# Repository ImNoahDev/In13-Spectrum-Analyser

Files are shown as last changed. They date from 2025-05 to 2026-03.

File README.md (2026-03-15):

# Nixie tube spectrum analyser

Warning: this is currently untested

I have designed an audio spectrum analyser that breaks an audio signal down into 7 frequency bands and displays each band on an in13 nixie tube. My project has Wifi allowing for smart home control. My project has a volume (changes sensitivity) and a brightness potentiometer. Each PCB takes a single audio signal input and 2 can be used for full stereo.

The case uses a laser cut kerf bend to allow the wrap around sheet to be cut in a single part. 

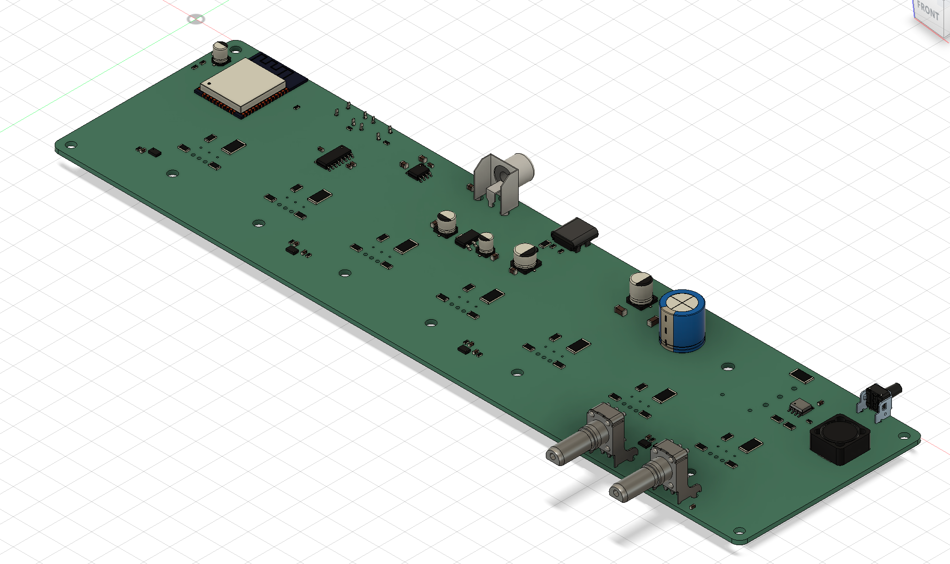
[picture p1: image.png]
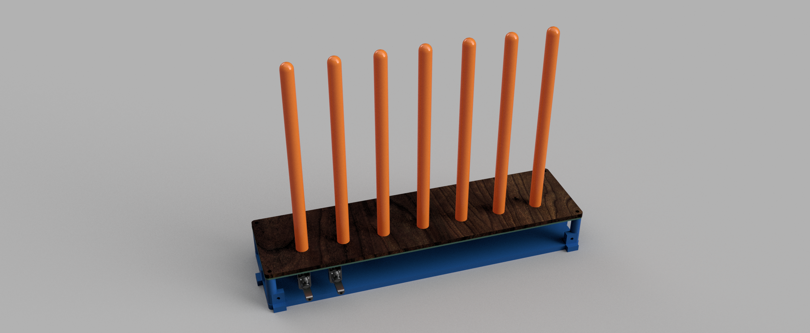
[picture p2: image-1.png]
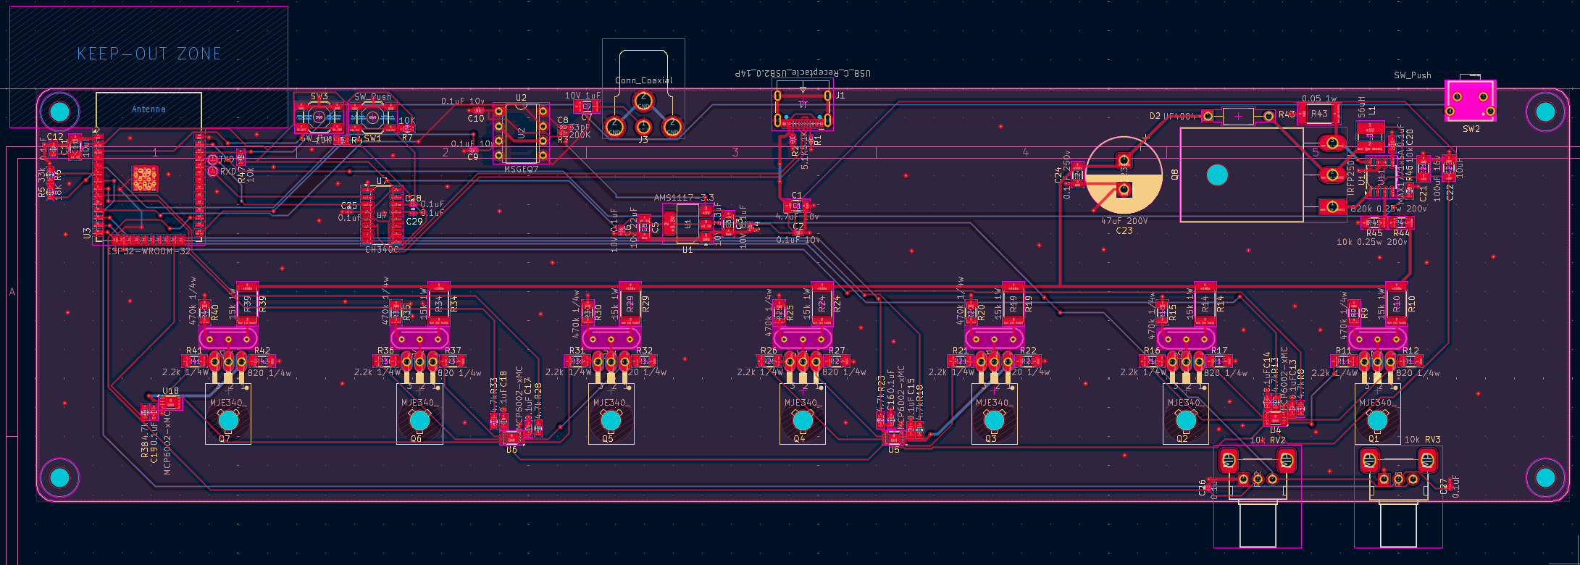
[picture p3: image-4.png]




## Assembly instructions.

First manufacture and assemble the PCB according to the KiCad files. Next 3d print the top and bottom parts of the case. place the PCB onto the standoffs of the case with layer B (with the least components) facing upwards. Place the top of the case on and screw all part onto the standoffs. Laser cut the Wrap around and screw it in to the bottom mounting holes of the case while wrapping around the case to give a wooden front finish.

Code can be flashed through the USB port due to the built in USB-Serial converter.

## BOM

Note this is for 2x units (Left and Right) because most PCB manufacturers require at least 2 assembled and the price is not significantly more for 2 vs 1. This allows one per audio channel. The price of the tubes also wildly swings so I have put a placeholder value in that is roughly correct (depending on where you get them).

| Part name | Cost | Use | URL |
| --- | --- | --- | --- |
| PCB Manufacture | $11.20  | PCB | jlpcb.com |
| Economic PCBA | $66.22  | Assemble PCB | jlpcb.com |
| Components (PCBA) | $61.93  | Components for PCBA | jlpcb.com |
| Shipping | $15 | PCB shipping | jlpcb.com |
| In13 tubes | $200 | Tubes | Ebay |
| Total: | $343.35 | | |

| Comment | Designator | Footprint | Quantity |
| --- | --- | --- | --- |
| MJE340_ | Q4 | TO126 | 1 |
| 10uF | C22 | C_1206_3216Metric | 1 |
| 4.7k | R38 | R_0603_1608Metric | 1 |
| 15k 1W | R14 | R_2512_6332Metric | 1 |
| 820k 0.25w 200v | R44 | R_1206_3216Metric | 1 |
| 820 1/4w | R22 | R_1206_3216Metric | 1 |
| 0.1uF | C28 | C_0201_0603Metric | 1 |
| 10v 22uF | C5 | C_1206_3216Metric | 1 |
| 10uF | C11 | C_1206_3216Metric | 1 |
| 15k 1W | R34 | R_2512_6332Metric | 1 |
| USB_C_Receptacle_USB2.0_14P | J1 | USB_C_Receptacle_HCTL_HC-TYPE-C-16P-01A | 1 |
| SW_Push | SW2 | 4312560387X6 | 1 |
| MJE340_ | Q2 | TO126 | 1 |
| 4.7k | R8 | R_0603_1608Metric | 1 |
| 0.05 1w | R43 | R_2512_6332Metric | 1 |
| 0.1uF | C15 | C_0603_1608Metric | 1 |
| ESP32-WROOM-32 | U3 | ESP32-WROOM-32 | 1 |
| 15k 1W | R19 | R_2512_6332Metric | 1 |
| 2.2k 1/4W | R26 | R_1206_3216Metric | 1 |
| 0.1uF | C27 | C_0201_0603Metric | 1 |
| 0.1uF | C13 | C_0603_1608Metric | 1 |
| 2.2k 1/4W | R16 | R_1206_3216Metric | 1 |
| 2.2k 1/4W | R36 | R_1206_3216Metric | 1 |
| 10k | RV2 | Potentiometer_Alps_RK09K_Single_Horizontal | 1 |
| MSGEQ7 | U2 | DIP-8_W7.62mm | 1 |
| 0.1uf | C25 | C_0201_0603Metric | 1 |
| SW_Push | SW3 | SW_SPST_SKQG_WithStem | 1 |
| 4.7k | R33 | R_0603_1608Metric | 1 |
| 820 1/4w | R37 | R_1206_3216Metric | 1 |
| MCP6002-xMC | U5 | DFN-8-1EP_3x2mm_P0.5mm_EP1.75x1.45mm | 1 |
| 2.2k 1/4W | R31 | R_1206_3216Metric | 1 |
| IRFP250N | Q8 | TO-247-3_Horizontal_TabDown | 1 |
| 56 uH | L1 | L_Ferrocore_DLG-0403 | 1 |
| 10k | R46 | R_0603_1608Metric | 1 |
| 200K | R3 | R_0402_1005Metric | 1 |
| 4.7k | R18 | R_0603_1608Metric | 1 |
| 820 1/4w | R27 | R_1206_3216Metric | 1 |
| MJE340_ | Q1 | TO126 | 1 |
| 0.1uF 10v | C10 | C_0402_1005Metric | 1 |
| 4.7k | R23 | R_0603_1608Metric | 1 |
| MJE340_ | Q6 | TO126 | 1 |
| 4.7uF 10v | C1 | C_1206_3216Metric | 1 |
| 15k 1W | R24 | R_2512_6332Metric | 1 |
| 10K | R7 | R_0603_1608Metric | 1 |
| MJE340_ | Q3 | TO126 | 1 |
| 0.1uF | C14 | C_0603_1608Metric | 1 |
| 0.1uF | C19 | C_0603_1608Metric | 1 |
| 0.1uF | C26 | C_0201_0603Metric | 1 |
| 100uF 16v | C21 | C_1206_3216Metric | 1 |
| 10V 1uF | C7 | C_1206_3216Metric | 1 |
| 10V 0.1uF | C4 | C_0402_1005Metric | 1 |
| MCP6002-xMC | U4 | DFN-8-1EP_3x2mm_P0.5mm_EP1.75x1.45mm | 1 |
| 0.1uF | C17 | C_0603_1608Metric | 1 |
| 470k 1/4w | R40 | R_1206_3216Metric | 1 |
| 820 1/4w | R42 | R_1206_3216Metric | 1 |
| 0.1uF | C16 | C_0603_1608Metric | 1 |
| 10k 0.25w 200v | R45 | R_1206_3216Metric | 1 |
| 15k 1W | R10 | R_2512_6332Metric | 1 |
| 470k 1/4w | R20 | R_1206_3216Metric | 1 |
| 47uF 200V | C23 | CP_Radial_D13.0mm_P5.00mm | 1 |
| SW_Push | SW1 | SW_SPST_SKQG_WithStem | 1 |
| RXD | TP2 | TestPoint_Pad_D1.0mm | 1 |
| 10K | R4 | R_0603_1608Metric | 1 |
| 5.1K | R1 | R_0402_1005Metric | 1 |
| 470k 1/4w | R25 | R_1206_3216Metric | 1 |
| 820 1/4w | R17 | R_1206_3216Metric | 1 |
| 470k 1/4w | R30 | R_1206_3216Metric | 1 |
| 10V 0.1uF | C6 | C_0402_1005Metric | 1 |
| 5.1K | R2 | R_0402_1005Metric | 1 |
| 470k 1/4w | R15 | R_1206_3216Metric | 1 |
| 0.1uF 10v | C9 | C_0402_1005Metric | 1 |
| 4.7k | R13 | R_0603_1608Metric | 1 |
| 10k | R47 | R_0603_1608Metric | 1 |
| TXD | TP1 | TestPoint_Pad_D1.0mm | 1 |
| 820 1/4w | R12 | R_1206_3216Metric | 1 |
| 4.7k | R28 | R_0603_1608Metric | 1 |
| 470k 1/4w | R9 | R_1206_3216Metric | 1 |
| 10k | RV3 | Potentiometer_Alps_RK09K_Single_Horizontal | 1 |
| MAX1771xSA | U11 | SO-8_3.9x4.9mm_P1.27mm | 1 |
| 2.2k 1/4W | R21 | R_1206_3216Metric | 1 |
| 18K | R5 | R_0603_1608Metric | 1 |
| 33k | R6 | R_0603_1608Metric | 1 |
| CH340C | U7 | SOIC-16_3.9x9.9mm_P1.27mm | 1 |
| MJE340_ | Q5 | TO126 | 1 |
| UF4004 | D2 | DIOAD1055W87L533D272 | 1 |
| 0.1uF | C18 | C_0603_1608Metric | 1 |
| 10V 3.3uF | C3 | C_1206_3216Metric | 1 |
| 2.2k 1/4W | R41 | R_1206_3216Metric | 1 |
| 0.1uF | C12 | C_0603_1608Metric | 1 |
| 470k 1/4w | R35 | R_1206_3216Metric | 1 |
| MCP6002-xMC | U6 | DFN-8-1EP_3x2mm_P0.5mm_EP1.75x1.45mm | 1 |
| 15k 1W | R39 | R_2512_6332Metric | 1 |
| AMS1117-3.3 | U1 | SOT-223-3_TabPin2 | 1 |
| 0.1uF 10v | C2 | C_0402_1005Metric | 1 |
| 15k 1W | R29 | R_2512_6332Metric | 1 |
| Conn_Coaxial | J3 | RCA-Phono_CUI-Devices_RCJ-01X_Horizontal | 1 |
| 0.1uF | C20 | C_0603_1608Metric | 1 |
| 33pF | C8 | C_0402_1005Metric | 1 |
| 0.1uF | C29 | C_0201_0603Metric | 1 |
| MJE340_ | Q7 | TO126 | 1 |
| 0.1uF 250v | C24 | C_1206_3216Metric | 1 |
| 820 1/4w | R32 | R_1206_3216Metric | 1 |
| MCP6002-xMC | U18 | DFN-8-1EP_3x2mm_P0.5mm_EP1.75x1.45mm | 1 |
| 2.2k 1/4W | R11 | R_1206_3216Metric | 1 |

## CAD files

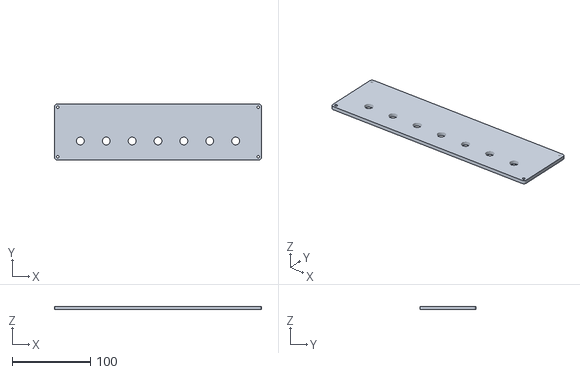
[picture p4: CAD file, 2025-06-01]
3D/Top Part.stl
264.2 x 71.1 x 4.00

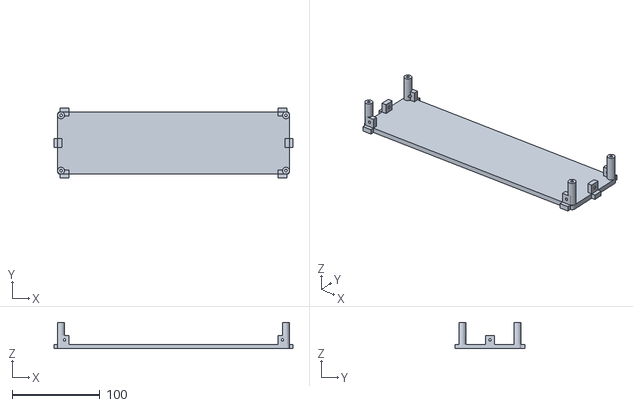
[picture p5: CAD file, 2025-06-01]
3D/Bottom part.stl
272.2 x 79.2 x 30.0

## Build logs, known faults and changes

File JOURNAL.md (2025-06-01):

Total: 25 hours

## Sunday 18 May (2hr)

I started to do initial research and then I begun to build a schematic. 

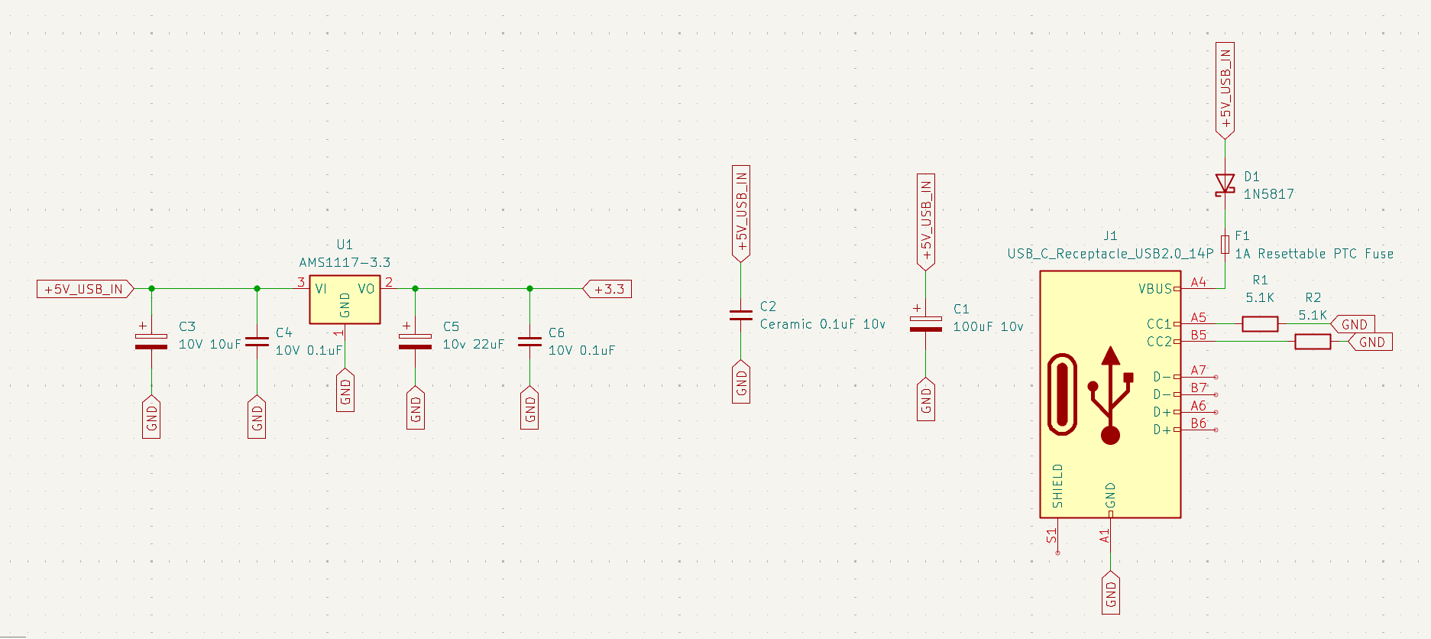
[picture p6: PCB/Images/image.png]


I started by adding a USB-C port. This port has the 5v input and ground. Pins CC1 and CC2 are both connected to ground with a 5.1k resistor. This allows me to tell the power source that I am requesting 5v power as a legacy device. 

I then added a decoupling capacitor between 5v and ground to smooth out the 5v supply. I also added a 0.1uF ceramic capacitor to perform High frequency decoupling on the power input. I added a resettable PTC fuse and Schottky diode to perform protection on the input and reverse polarity protection. I used a Schottky diode to minimise voltage drop.

I then added a 3.3v regulator to create a 3.3v rail for the ESP32 that will process the audio input. I chose a low dropout regulator and connected the inputs to my 5v system. I added a 10uF input capacitor to the input and a 22uF output capacitor for voltage smoothing. I then added 0.1uF ceramic caps to the input and output to perform high-frequency decoupling.

## Monday 19 May (2.5hr)

I researched how to spit my audio output into different channels. I ended up choosing a MSGEQ7 chip which splits the input audio into 7 bands.

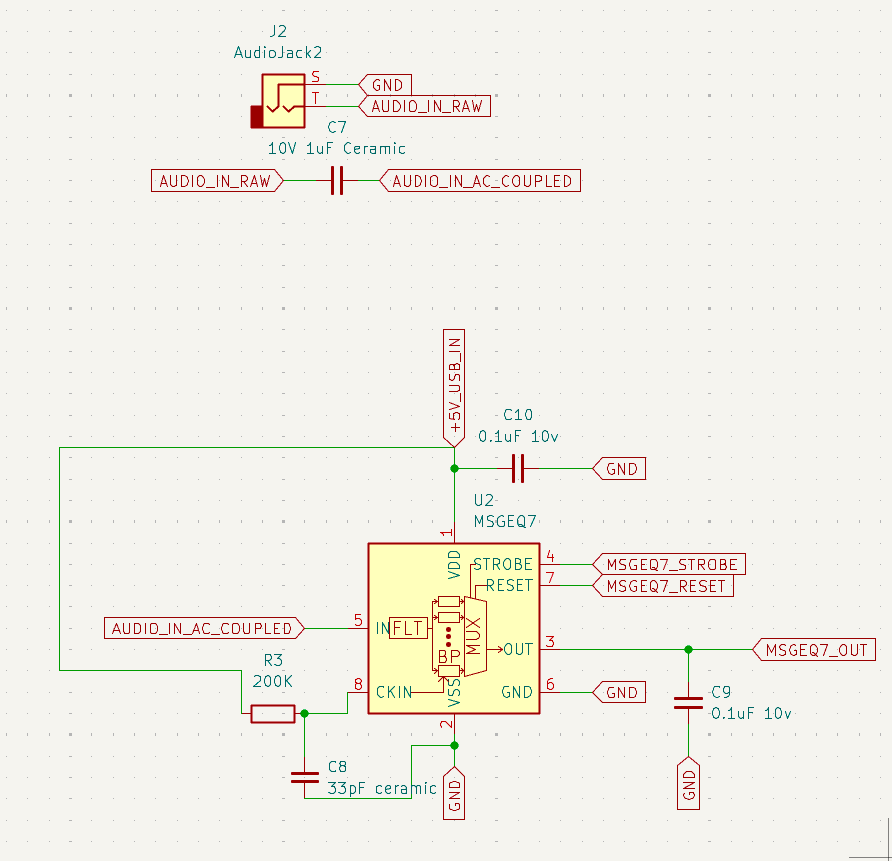
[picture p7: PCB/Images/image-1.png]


I start by taking the output from my audio jack and adding a coupling capacitor in serices to remove and DC offset from the audio signal, this is because the MSGEQ7 expects an AC audio signal. My design expects a line level input from an audio jack. 

The reset and strope pins of the MSGEQ7 are connected to labels to be controlled by the ESP32. The output of the MSGEQ7 get given to an ADC on the ESP32. An external capacitor has been added for the oscilator in the MSGEQ7. An output filter capacitor has been added to provide stability to the output and a decoupling capacitor has been added to decouple to power supply. 

## Monday 19 May (2hr)

I added the esp32 control board here. I chose an ESP32 WROOM 32 dev module.

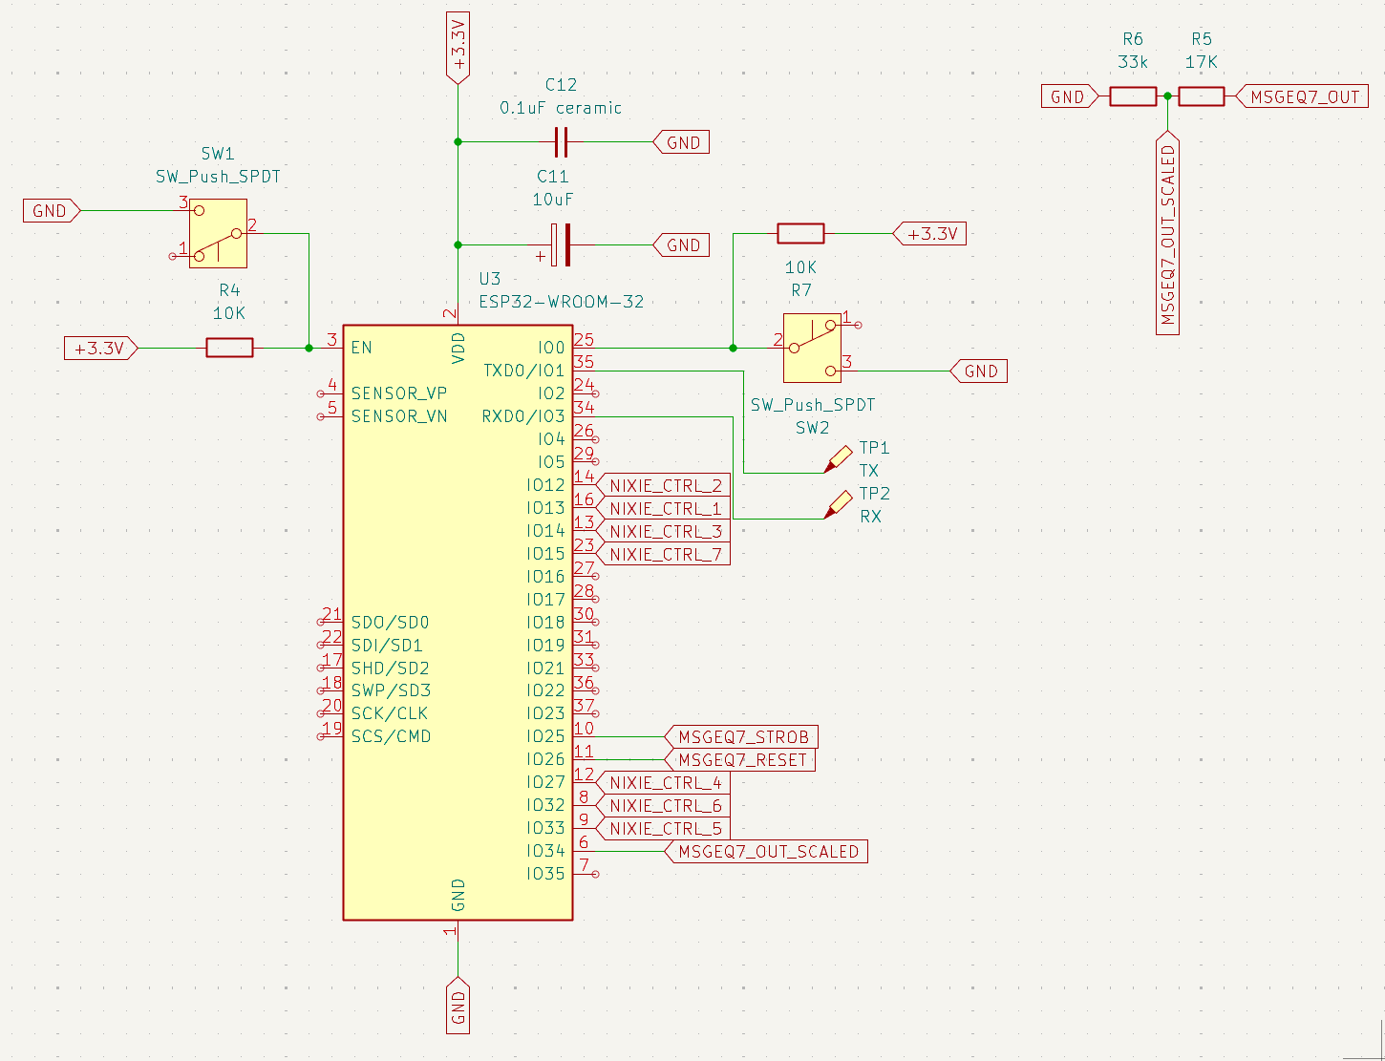
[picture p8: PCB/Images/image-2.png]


I started by powering the ESP32. This chip uses 3.3v and is therefore powered by my 3.3v rail. Ground is connected to my common ground rail. The EN pin is pulled to high with a button to connect it to ground and act as a reset button. I have 2 decoupling capacitors, these are an addition to the decoupling capacitors inside the model but can't hurt so why not! The MSGEQ7 output is connected to an ADC input with a voltage divider to bring the 0-5v signal down to a 0-3.3v signal. The strobe and reset pins from the MSGEQ7 are also connected to the ESP32 so they can be controlled via software. The 8 nixie tube control pins are connected to PWM capable outputs on the ESP32 to allow for dimming. The TXD and RXD pins are connected to test points to allow for flashing of firmware. the IO0 pin is pulled down to GND by a button to enter flashing mode and is conencted to +3.3v via a pull up resistor by default.

The ESP32 can be flashed from the test points using a USB-to-Serial converter.

## Monday 19 May (3hr)

I created the driver circuity for the nixie tubes. This has been done assuming the 140v is on the +140v rail (I will add this circuitry later).

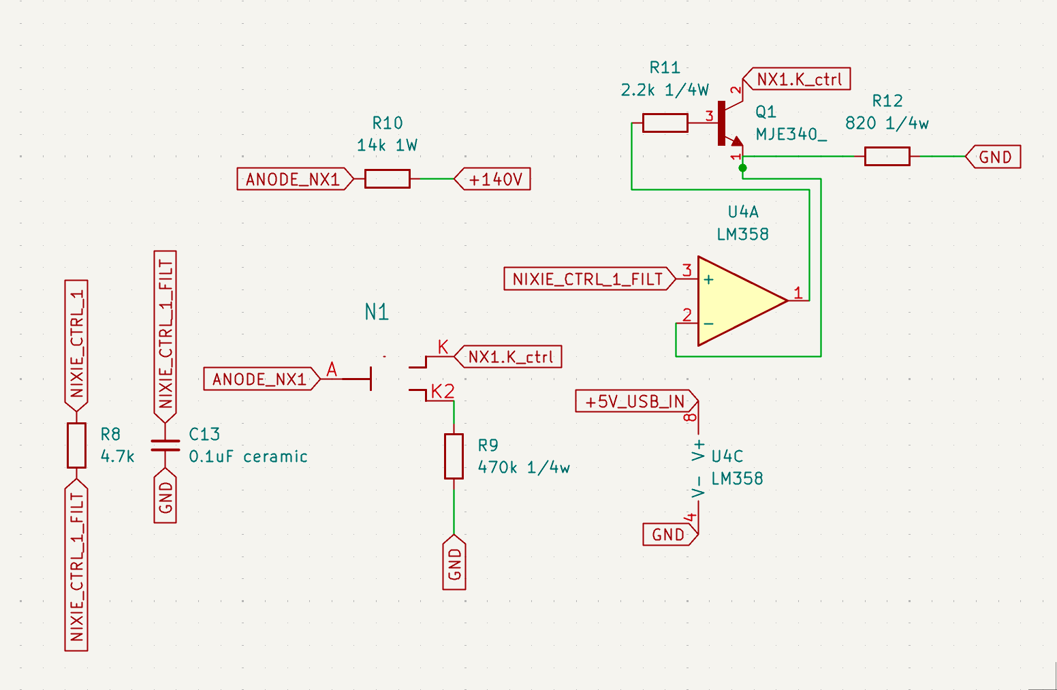
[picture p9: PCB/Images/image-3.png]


I first created a low pass filter for the PWM Smoothing converting the PWM from the ESP32 into a smooth analogue voltage. I have a 4.7K resistor from the nixie control pin to create this low pass filter. I have also got a capacitor from the filtered output to ground as a minimum cut off. I have added my nixie tube and connected the control to the collector if the driver transistor and the aux to ground via an auxillary cathode resistor. The annode is connected to 140v via a 14k resistor. I have used an op-amp to buffer the nixie control frequency and drivbe an NPN transistor. I am using a high voltage NPN transistor. I also have a base and emittor resistor connected to the trnasistor. The emitter resistor sets the relationship between the nixie control output and the current in the cathode.

I then duplicated this design 7 times (one for each tube), changing the labels accordingly.

## Tuesday 20 May (3hr)

I created a power supply to boost my 5v to 140v to power the nixie tubes.

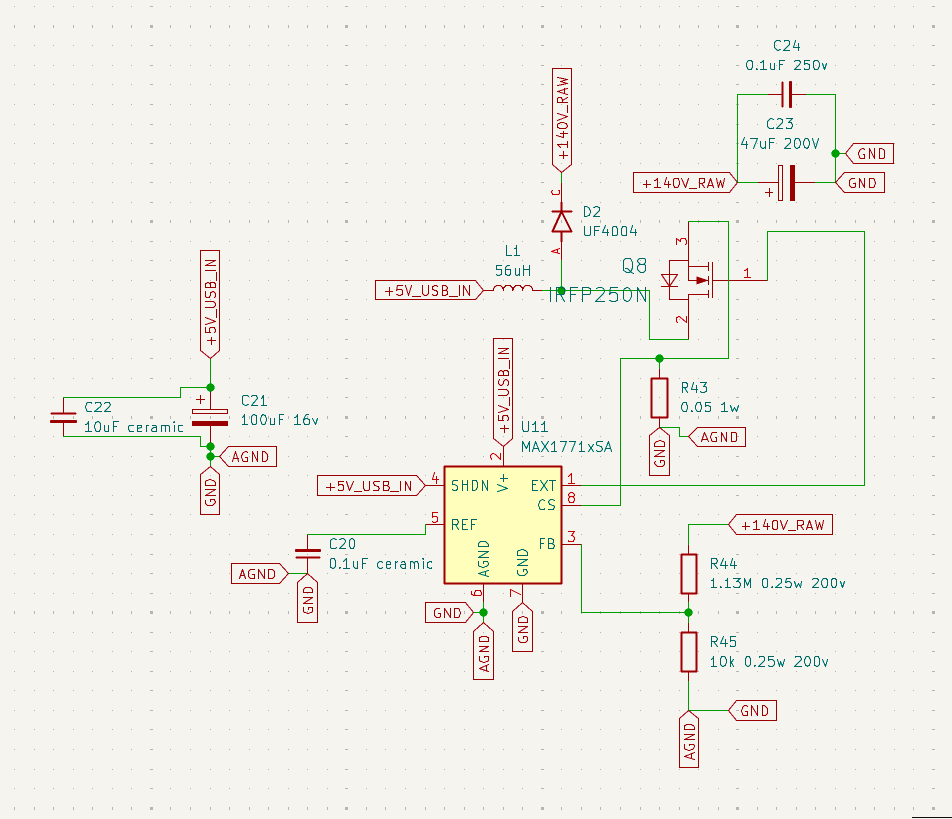
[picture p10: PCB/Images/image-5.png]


To create my 140v line, i am using a MAX1771 IC. This IC is commonplace on many nixie tube power boards and is therefore the obvious choice. I have performed input decoupling on the 5v power for the high voltage section. I am using an N channel mosfet which is driven by the MAX1771. The MAX1771 turns onm the mosfet allowing power to go through the inductor and through the mosfet to ground. The inductor opposes the change in current causing the current to ramp up linearly over time. The inductor stores its energy in its magnetic field. The diode is reverse biased during this phase, so no current can flow through it. The output capacitor is supplying current to the nixie tubes during this phase.

The MAX1771 turns off the mosfet. The current cannot change in the inductor instantaneously, this means the inductor tries to maintain current flow. The indyctor then reverses its polarity, the reversed voltage addes to the input voltage creating a higher voltage. The diode becomes forward biased allowing current to flow from the inductor to the output capacitor. The inductor then ramps down its current linearly. This cycle repeats to create my high voltage.

## Tuesday 20 May (1.5hr)

Small Changes have been made. I have added 2 potentiometers for volume and brightness control. I added a shutdown button and linked the shutdown rail on the MAX1771 to the ESP32 to allow it to shut off the high voltage when not in use. I have also done general schematic cleanup and I have added labels for readability. I also added a serial controller to allow me to write to the ESP32 through the USB-C port. I used a CH340C due to the minimal extra circuitry needed. I also grounded the USB-C shield.

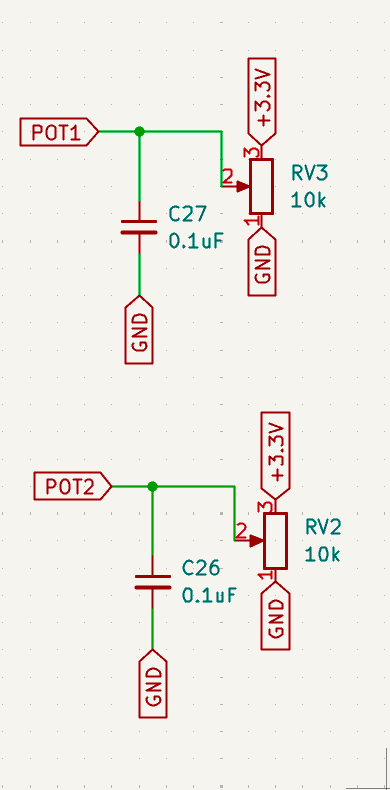
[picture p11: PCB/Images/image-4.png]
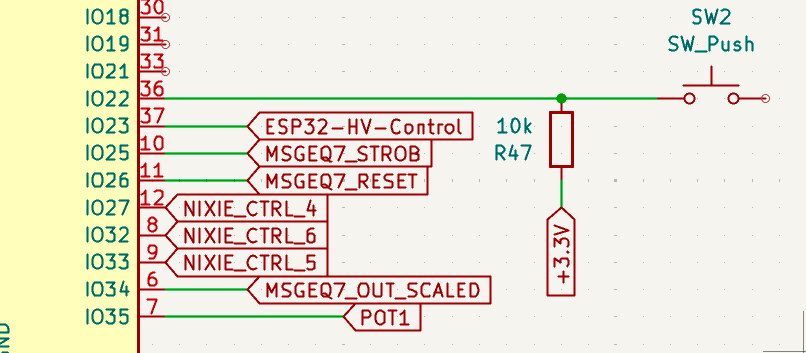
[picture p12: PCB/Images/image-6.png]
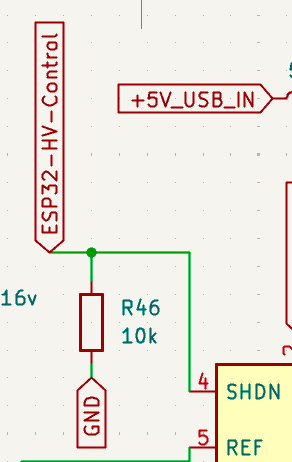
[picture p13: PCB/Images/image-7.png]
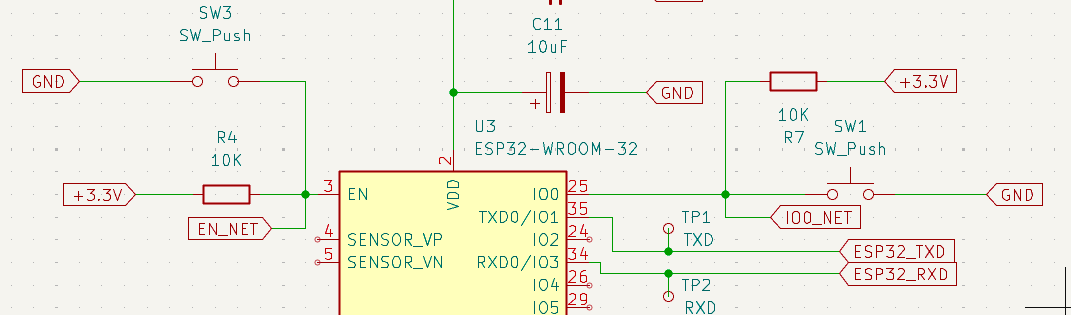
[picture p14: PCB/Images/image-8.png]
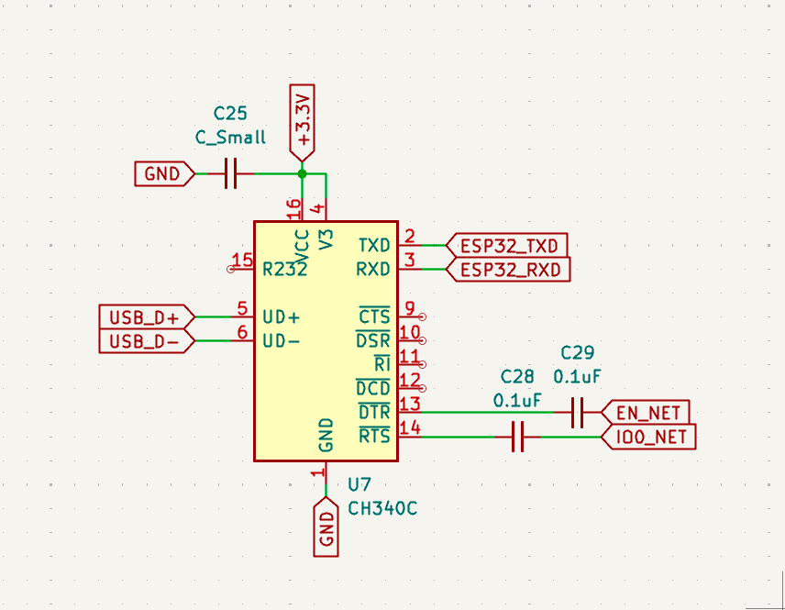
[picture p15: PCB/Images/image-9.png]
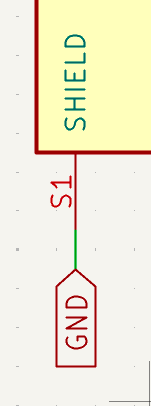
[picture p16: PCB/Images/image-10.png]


## Wednesday 20 May (5hr)

This was my first attempt at routing the PCB

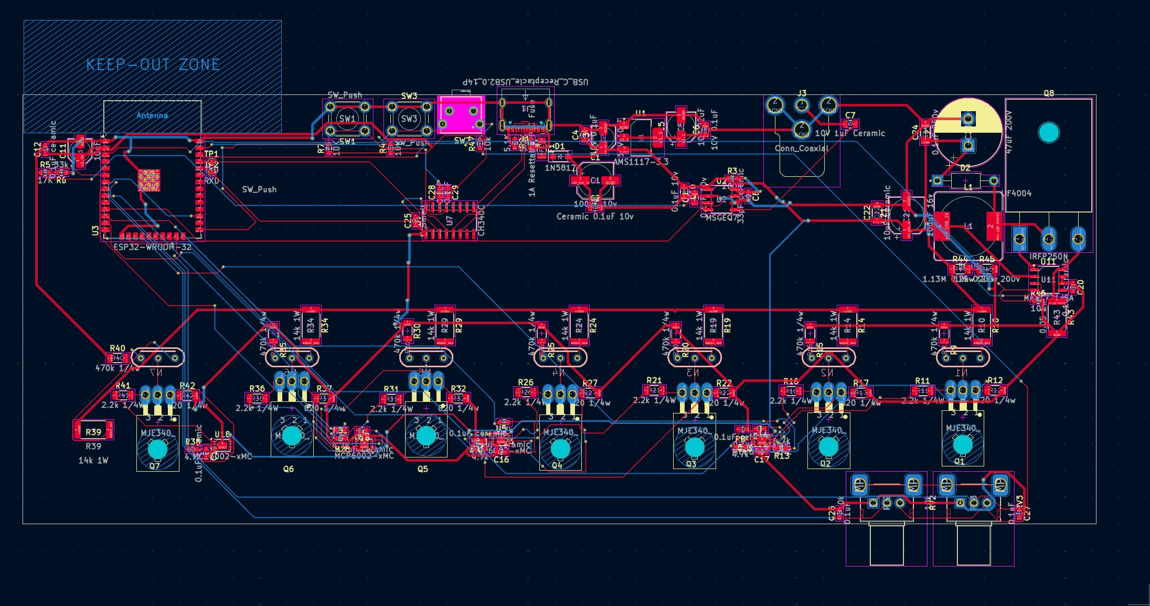
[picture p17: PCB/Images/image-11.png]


I learned from this first attempt that a ground plane would be invaluble. This proved my PCB was possible to route on a 2 layer PCB. Next time, I will make my PCB longer and use the bottom layer as a ground plane. I have my tubes on the bottom layer with electronics on the top to allow and large components to face down giving me more flexibility in my case design. In my next iteration I will also add mounting holes and rounded edges. Finally, I will attempt to use the freerouter autorouter on my next iteration with a new pcb layout.

## Thursday 20 May (4hr)

This is my second (and hopefully final) attempt at routing the PCB.

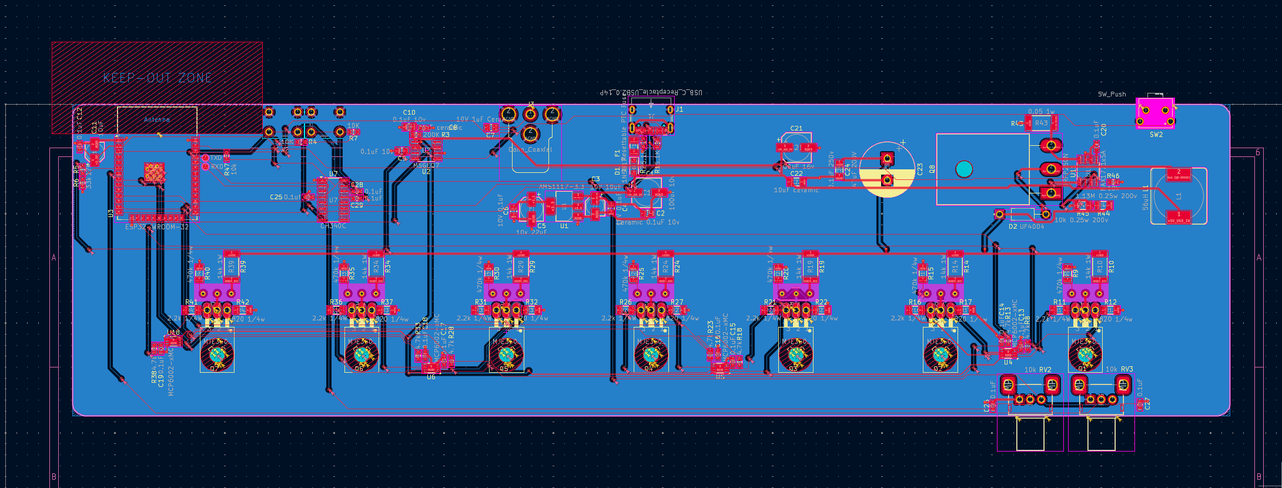
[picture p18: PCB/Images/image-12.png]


For this attempt, I used a ground plane on layer B to make routing easier. I also made the PCB longer to make it easier to route and to make the final assembly look better. I used freerouter to route this attempt as it gives a more optimised attempt than my manual attempt. After optimising the settings, freerouter was able to optimally route my PCB. I had to manually route my ground traces to the ground plane as freerouter does not support this automatically.

## Wed 28 May (2.5hr)

I have added a second ground plane to the top of the pcb. I have also added standoffs to the corners. I have cleaned up the schematic.

I designed a case for my model using a combination of laser cut and 3d printed parts. My case uses a laser cut kerf bend to allow the sides to be cut as a single piece and then this piece can be wrapped around.

Added readme.md

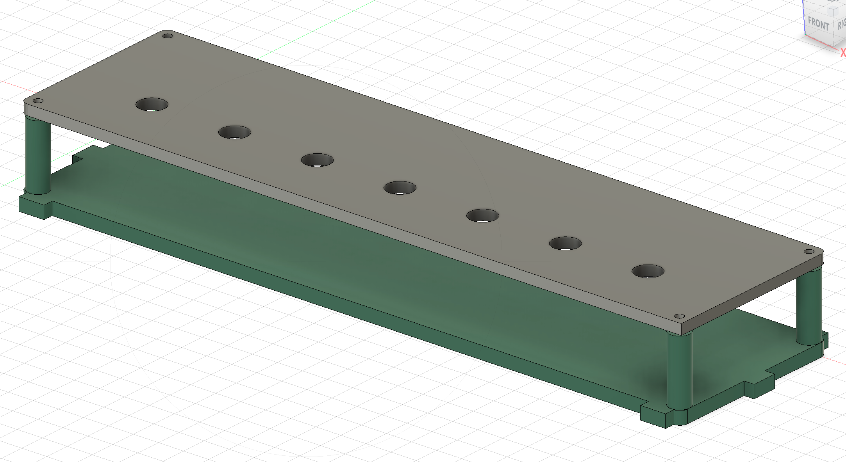
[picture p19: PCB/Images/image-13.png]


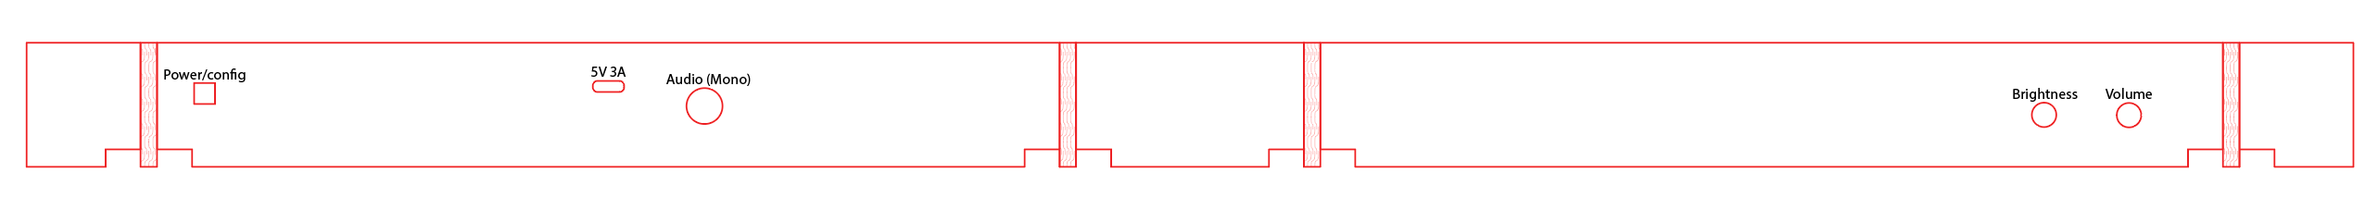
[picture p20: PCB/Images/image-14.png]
 

## Wed 28 May (2.5hr)

I replaced certain footprints with ones available at JLPCB and re-routed.

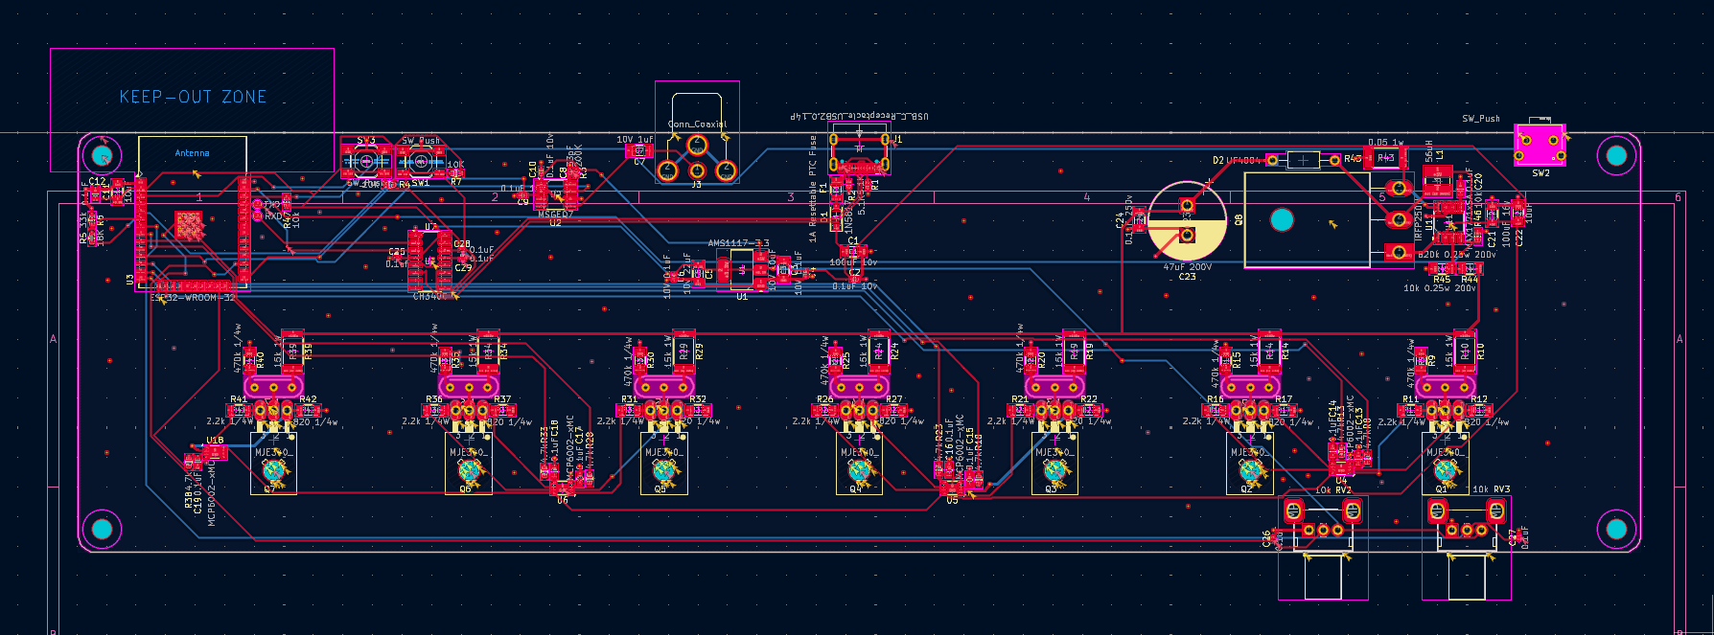
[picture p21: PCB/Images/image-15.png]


## Sun 1 June (1hr)

Added code for basic functionality and add mounting holes to the case to remove the need for glue.

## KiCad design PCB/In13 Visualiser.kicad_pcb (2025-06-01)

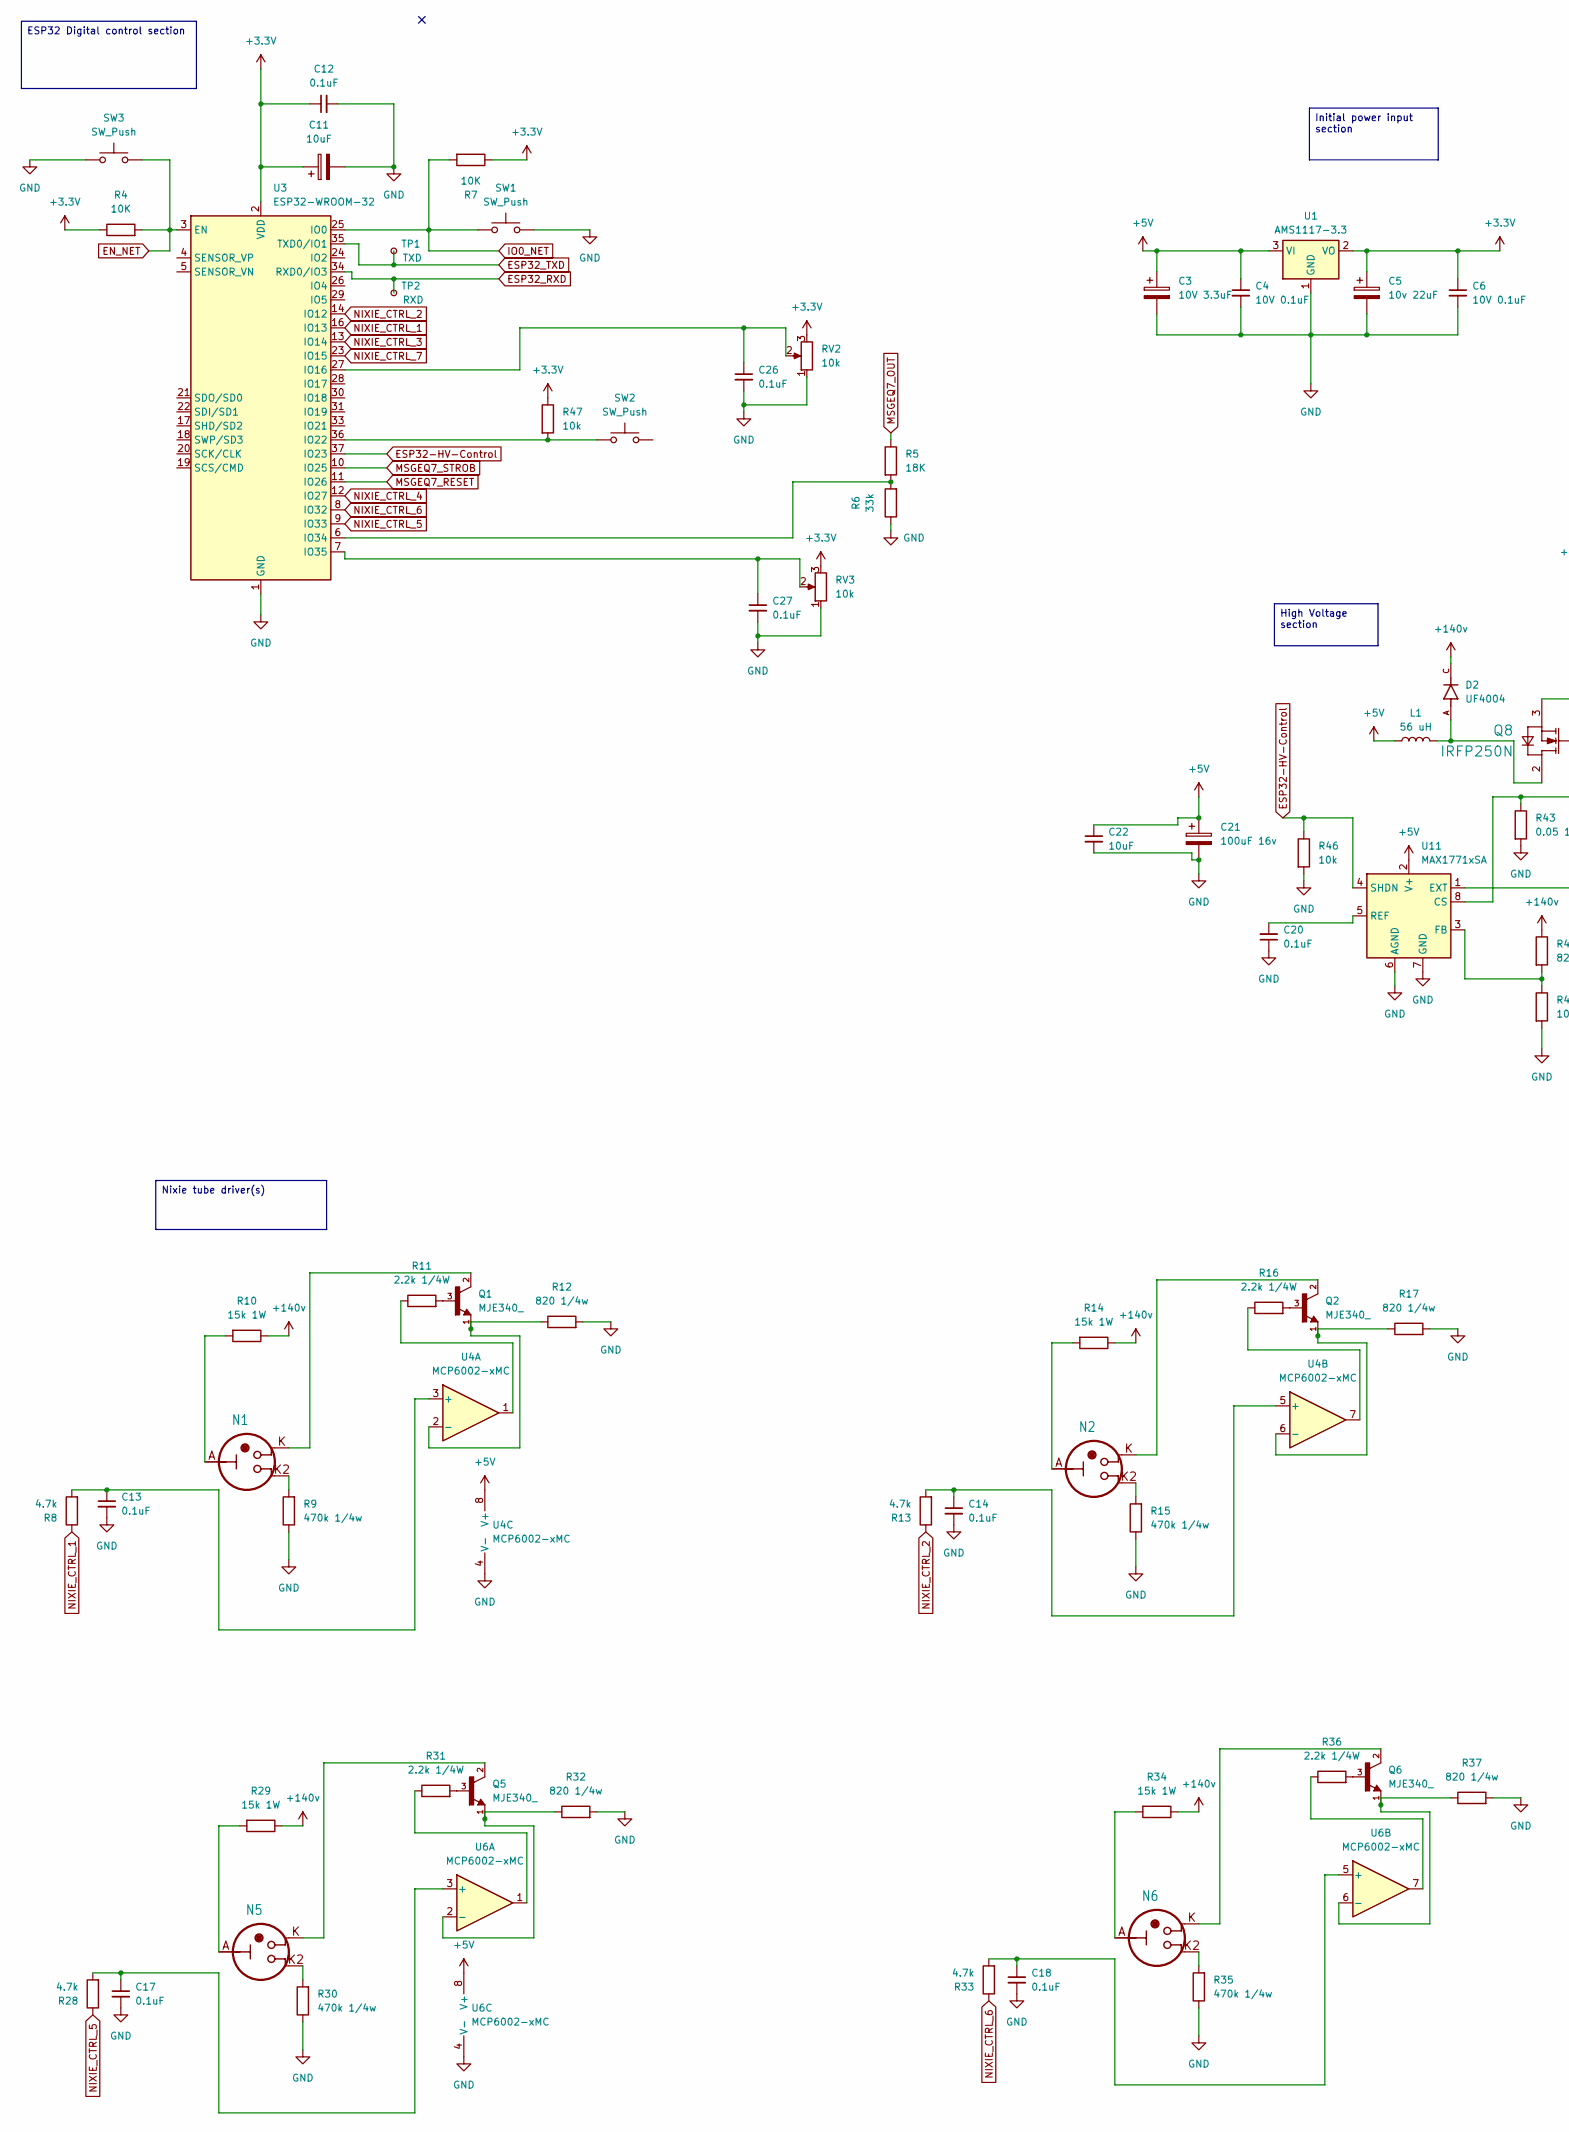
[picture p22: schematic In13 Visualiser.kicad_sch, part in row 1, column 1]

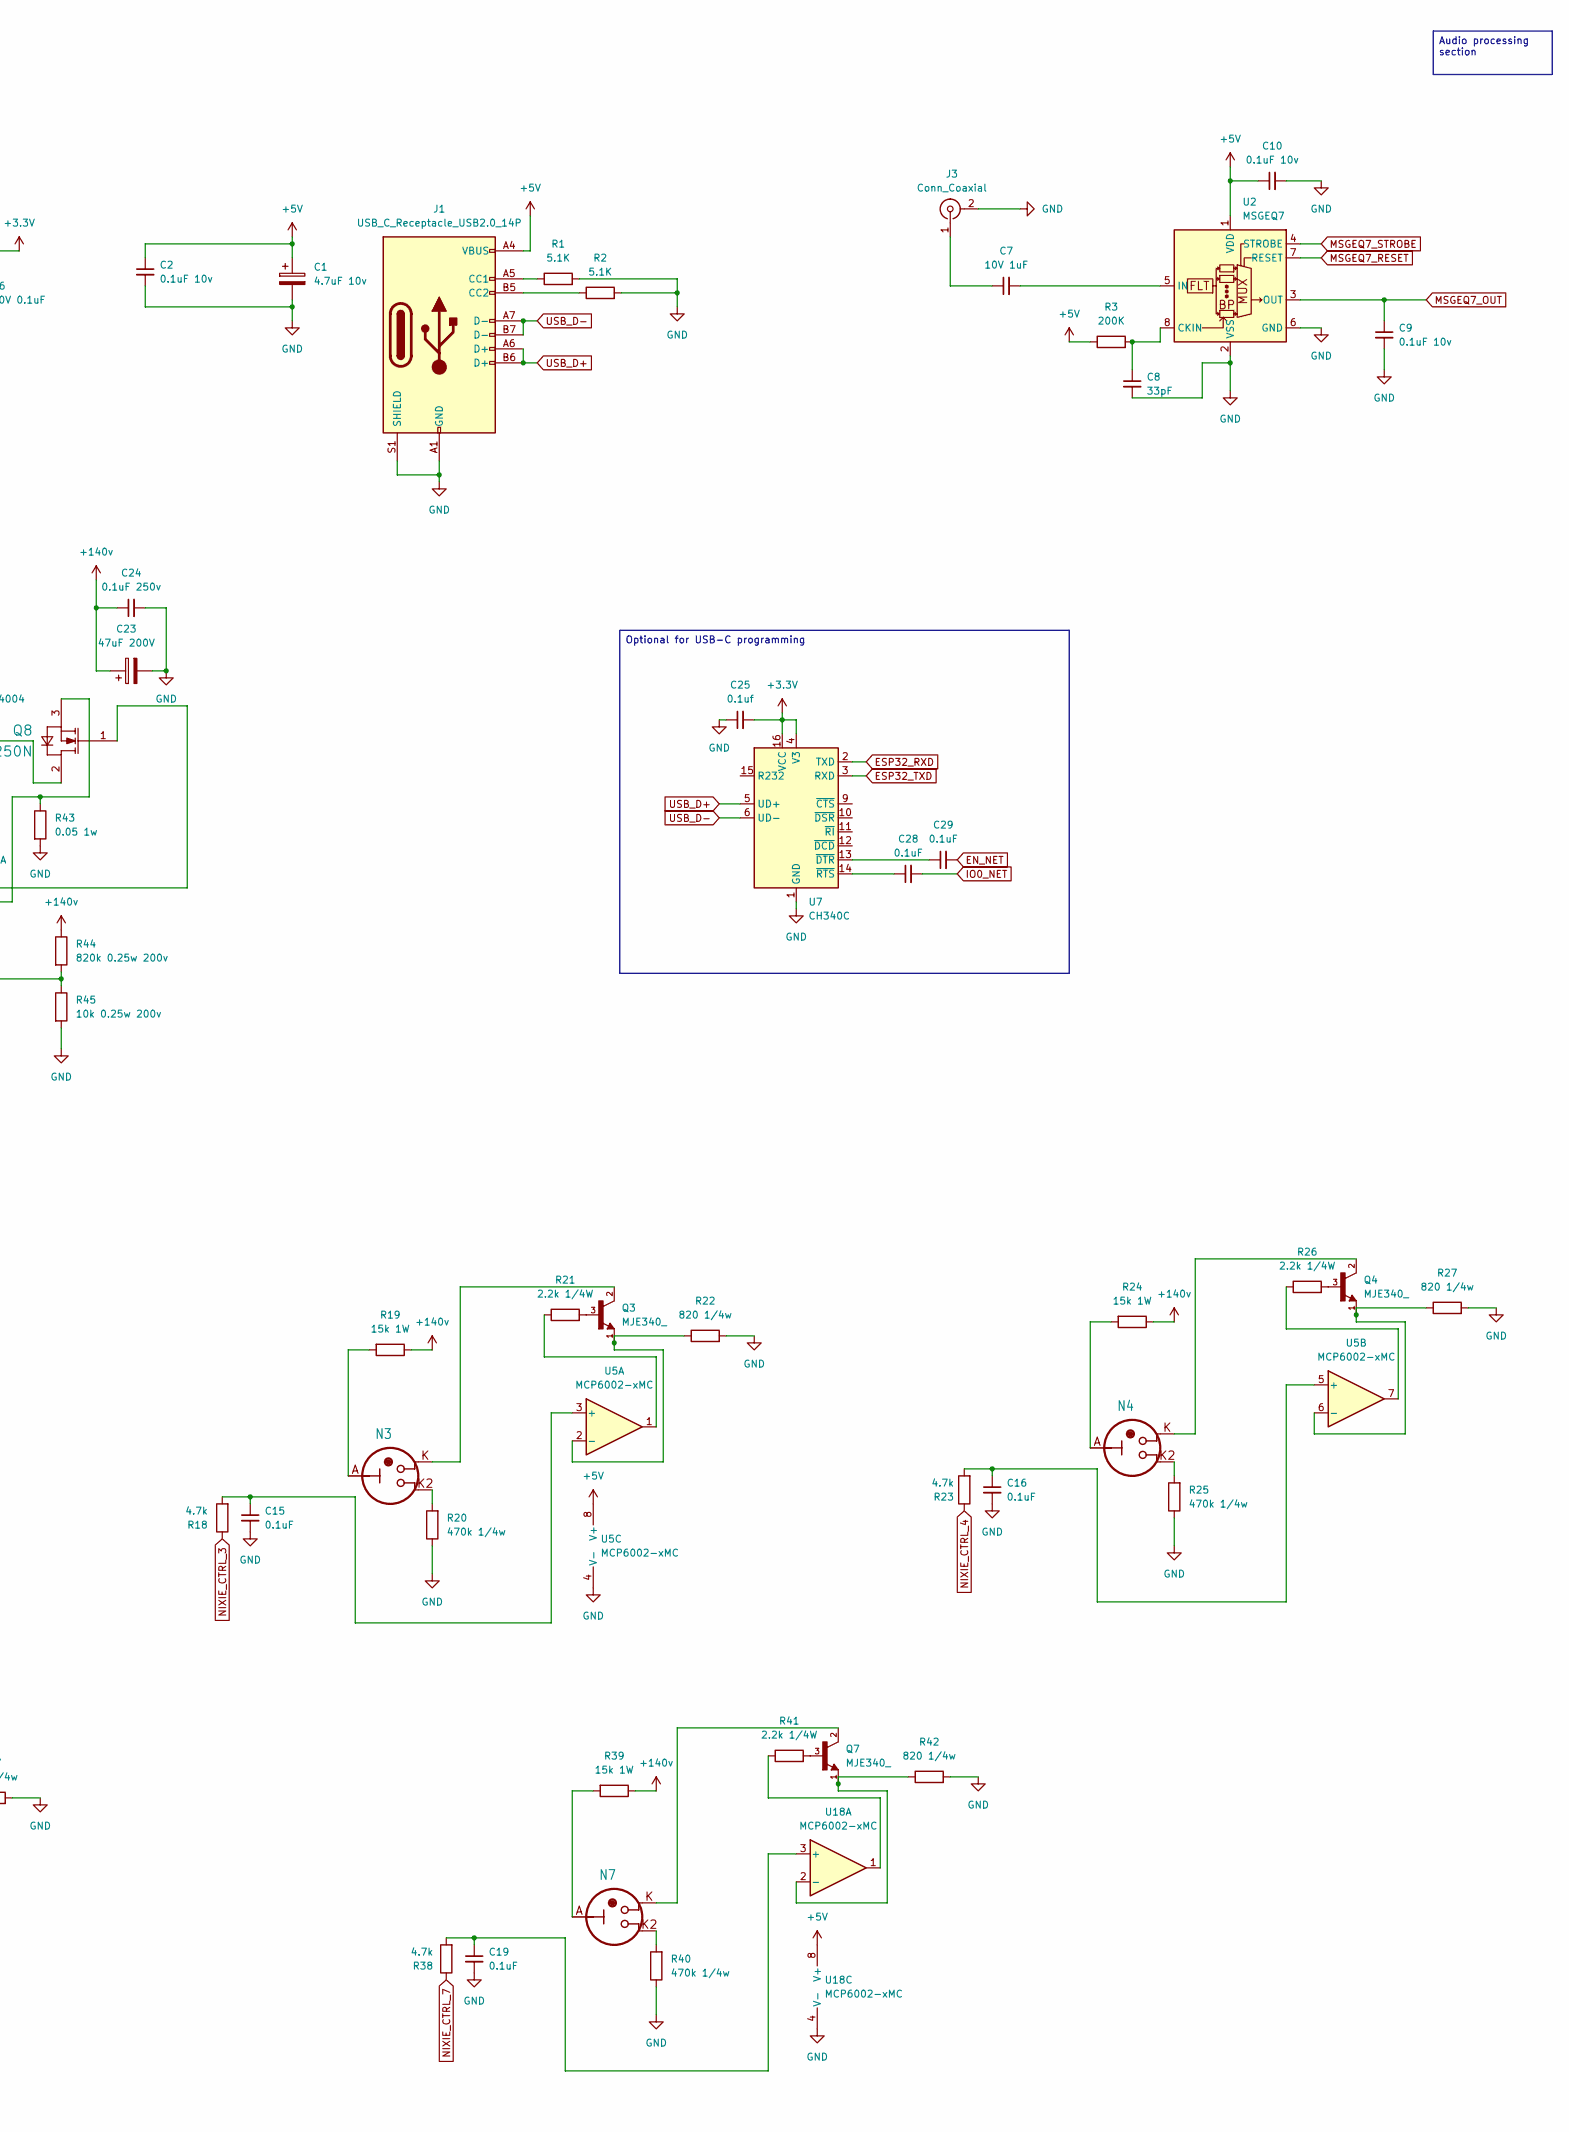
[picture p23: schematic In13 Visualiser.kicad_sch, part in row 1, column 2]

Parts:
C1: 4.7uF 10v; C_1206_3216Metric
C2, C9, C10: 0.1uF 10v; C_0402_1005Metric
C3: 10V 3.3uF; C_1206_3216Metric
C4, C6: 10V 0.1uF; C_0402_1005Metric
C5: 10v 22uF; C_1206_3216Metric
C7: 10V 1uF; C_1206_3216Metric
C8: 33pF; C_0402_1005Metric
C11, C22: 10uF; C_1206_3216Metric
C12, C13, C14, C15, C16, C17, C18, C19, C20: 0.1uF; C_0603_1608Metric
C21: 100uF 16v; C_1206_3216Metric
C23: 47uF 200V; CP_Radial_D13.0mm_P5.00mm
C24: 0.1uF 250v; C_1206_3216Metric
C25: 0.1uf; C_0201_0603Metric
C26, C27, C28, C29: 0.1uF; C_0201_0603Metric
D2: UF4004; DIOAD1055W87L533D272; PARTREV N/A
J1: USB_C_Receptacle_USB2.0_14P; USB_C_Receptacle_HCTL_HC-TYPE-C-16P-01A
J3: Conn_Coaxial; RCA-Phono_CUI-Devices_RCJ-01X_Horizontal
L1: 56 uH; L_Ferrocore_DLG-0403
N1, N2, N3, N4, N5, N6, N7: nixies-us-IN-13
Q1, Q2, Q3, Q4, Q5, Q6, Q7: MJE340_; TO126
Q8: IRFP250N; TO-247-3_Horizontal_TabDown
R1, R2: 5.1K; R_0402_1005Metric
R3: 200K; R_0402_1005Metric
R4, R7: 10K; R_0603_1608Metric
R5: 18K; R_0603_1608Metric
R6: 33k; R_0603_1608Metric
R8, R13, R18, R23, R28, R33, R38: 4.7k; R_0603_1608Metric
R9, R15, R20, R25, R30, R35, R40: 470k 1/4w; R_1206_3216Metric
R10, R14, R19, R24, R29, R34, R39: 15k 1W; R_2512_6332Metric
R11, R16, R21, R26, R31, R36, R41: 2.2k 1/4W; R_1206_3216Metric
R12, R17, R22, R27, R32, R37, R42: 820 1/4w; R_1206_3216Metric
R43: 0.05 1w; R_2512_6332Metric
R44: 820k 0.25w 200v; R_1206_3216Metric
R45: 10k 0.25w 200v; R_1206_3216Metric
R46, R47: 10k; R_0603_1608Metric
RV2, RV3: 10k; Potentiometer_Alps_RK09K_Single_Horizontal
SW1, SW3: SW_Push; SW_SPST_SKQG_WithStem
SW2: SW_Push; 4312560387X6
TP1: TXD; TestPoint_Pad_D1.0mm
TP2: RXD; TestPoint_Pad_D1.0mm
U1: AMS1117-3.3; SOT-223-3_TabPin2
U2: MSGEQ7; DIP-8_W7.62mm
U3: ESP32-WROOM-32
U4, U5, U6, U18: MCP6002-xMC; DFN-8-1EP_3x2mm_P0.5mm_EP1.75x1.45mm
U7: CH340C; SOIC-16_3.9x9.9mm_P1.27mm
U11: MAX1771xSA; SO-8_3.9x4.9mm_P1.27mm

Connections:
+3.3V: C5.1, C6.1, C11.1, C12.1, C25.2, R4.1, R7.1, R47.1, RV2.3, RV3.3, U1.2 (VO), U3.2 (VDD), U7.4 (V3), U7.16 (VCC)
+5V: C1.1, C2.1, C3.1, C4.1, C10.1, C21.1, C22.1, J1.A4 (VBUS), J1.A9 (VBUS), J1.B4 (VBUS), J1.B9 (VBUS), L1.1, R3.1, U1.3 (VI), U2.1 (VDD), U4.8 (V+), U5.8 (V+), U6.8 (V+), U11.2 (V+), U18.8 (V+)
+140v: C23.1, C24.1, D2.C, R10.1, R14.1, R19.1, R24.1, R29.1, R34.1, R39.1, R44.1
EN_NET: C29.2, R4.2, SW3.2, U3.3 (EN)
ESP32-HV-Control: R46.1, U3.37 (IO23), U11.4 (SHDN)
ESP32_RXD: TP2.1, U3.34 (RXD0/IO3), U7.2 (TXD)
ESP32_TXD: TP1.1, U3.35 (TXD0/IO1), U7.3 (RXD)
GND: C1.2, C2.2, C3.2, C4.2, C5.2, C6.2, C8.2, C9.2, C10.2, C11.2, C12.2, C13.2, C14.2, C15.2, C16.2, C17.2, C18.2, C19.2, C20.1, C21.2, C22.2, C23.2, C24.2, C25.1, C26.2, C27.2, J1.A1 (GND), J1.A12 (GND), J1.B1 (GND), J1.B12 (GND), J1.S1 (SHIELD), J3.2 (Ext), R1.2, R2.2, R6.1, R9.1, R12.2, R15.1, R17.2, R20.1, R22.2, R25.1, R27.2, R30.1, R32.2, R35.1, R37.2, R40.1, R42.2, R43.2, R45.2, R46.2, RV2.1, RV3.1, SW1.2, SW3.1, U1.1 (GND), U2.2 (VSS), U2.6 (GND), U3.1 (GND), U3.15 (GND), U3.38 (GND), U3.39 (GND), U4.4 (V-), U4.9 (V-), U5.4 (V-), U5.9 (V-), U6.4 (V-), U6.9 (V-), U7.1 (GND), U11.6 (AGND), U11.7 (GND), U18.4 (V-), U18.9 (V-)
IO0_NET: C28.2, R7.2, SW1.1, U3.25 (IO0)
MSGEQ7_OUT: C9.1, R5.1, U2.3 (OUT)
MSGEQ7_RESET: U2.7 (RESET), U3.11 (IO26)
MSGEQ7_STROB: U3.10 (IO25)
MSGEQ7_STROBE: U2.4 (STROBE)
NIXIE_CTRL_1: R8.1, U3.16 (IO13)
NIXIE_CTRL_2: R13.1, U3.14 (IO12)
NIXIE_CTRL_3: R18.1, U3.13 (IO14)
NIXIE_CTRL_4: R23.1, U3.12 (IO27)
NIXIE_CTRL_5: R28.1, U3.9 (IO33)
NIXIE_CTRL_6: R33.1, U3.8 (IO32)
NIXIE_CTRL_7: R38.1, U3.23 (IO15)
unnamed: J1.A5 (CC1), R1.1
unnamed: J1.B5 (CC2), R2.1
unnamed: C7.1, J3.1 (In)
unnamed: N1.A, R10.2
unnamed: N1.K2, R9.2
unnamed: N1.K, Q1.2
unnamed: N2.A, R14.2
unnamed: N2.K2, R15.2
unnamed: N2.K, Q2.2
unnamed: N3.A, R19.2
unnamed: N3.K2, R20.2
unnamed: N3.K, Q3.2
unnamed: N4.A, R24.2
unnamed: N4.K2, R25.2
unnamed: N4.K, Q4.2
unnamed: N5.A, R29.2
unnamed: N5.K2, R30.2
unnamed: N5.K, Q5.2
unnamed: N6.A, R34.2
unnamed: N6.K2, R35.2
unnamed: N6.K, Q6.2
unnamed: N7.A, R39.2
unnamed: N7.K2, R40.2
unnamed: N7.K, Q7.2
unnamed: Q1.3, R11.2
unnamed: Q2.3, R16.2
unnamed: Q3.3, R21.2
unnamed: Q4.3, R26.2
unnamed: Q5.3, R31.2
unnamed: Q6.3, R36.2
unnamed: Q7.3, R41.2
unnamed: D2.A, L1.2, Q8.2 (DRAIN)
unnamed: Q8.1 (GATE), U11.1 (EXT)
unnamed: Q8.3 (SOURCE), R43.1, U11.8 (CS)
unnamed: R11.1, U4.1
unnamed: R16.1, U4.7
unnamed: R21.1, U5.1
unnamed: R26.1, U5.7
unnamed: R31.1, U6.1
unnamed: R36.1, U6.7
unnamed: R41.1, U18.1
unnamed: C8.1, R3.2, U2.8 (CKIN)
unnamed: C7.2, U2.5 (IN)
unnamed: C26.1, RV2.2, U3.27 (IO16)
unnamed: R47.2, SW2.1, U3.36 (IO22)
unnamed: R5.2, R6.2, U3.6 (IO34)
unnamed: C27.1, RV3.2, U3.7 (IO35)
unnamed: C13.1, R8.2, U4.3 (+)
unnamed: Q1.1, R12.1, U4.2 (-)
unnamed: C14.1, R13.2, U4.5 (+)
unnamed: Q2.1, R17.1, U4.6 (-)
unnamed: C15.1, R18.2, U5.3 (+)
unnamed: Q3.1, R22.1, U5.2 (-)
unnamed: C16.1, R23.2, U5.5 (+)
unnamed: Q4.1, R27.1, U5.6 (-)
unnamed: C17.1, R28.2, U6.3 (+)
unnamed: Q5.1, R32.1, U6.2 (-)
unnamed: C18.1, R33.2, U6.5 (+)
unnamed: Q6.1, R37.1, U6.6 (-)
unnamed: C29.1, U7.13 (~DTR)
unnamed: C28.1, U7.14 (~RTS)
unnamed: R44.2, R45.1, U11.3 (FB)
unnamed: C20.2, U11.5 (REF)
unnamed: C19.1, R38.2, U18.3 (+)
unnamed: Q7.1, R42.1, U18.2 (-)
USB_D+: J1.A6 (D+), J1.B6 (D+), U7.5 (UD+)
USB_D-: J1.A7 (D-), J1.B7 (D-), U7.6 (UD-)

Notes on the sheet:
Initial power input section
High Voltage section
Nixie tube driver(s)
ESP32 Digital control section
Audio processing section
Optional for USB-C programming

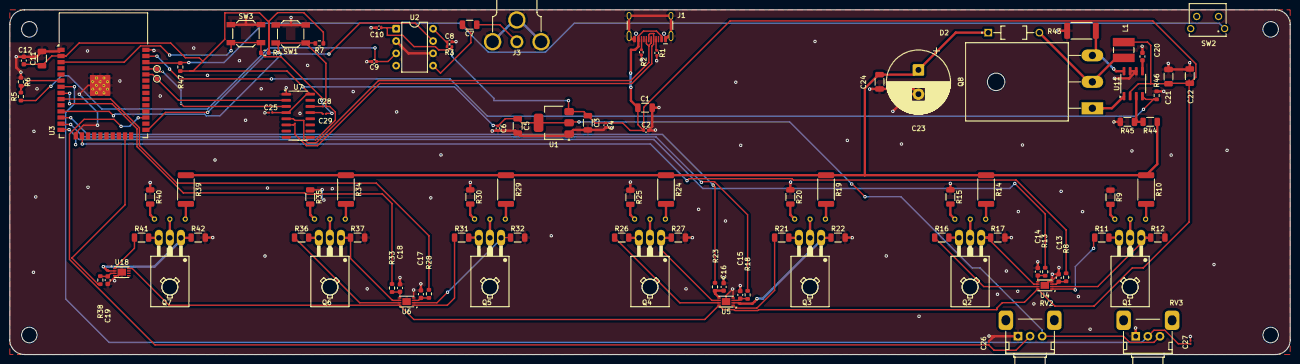
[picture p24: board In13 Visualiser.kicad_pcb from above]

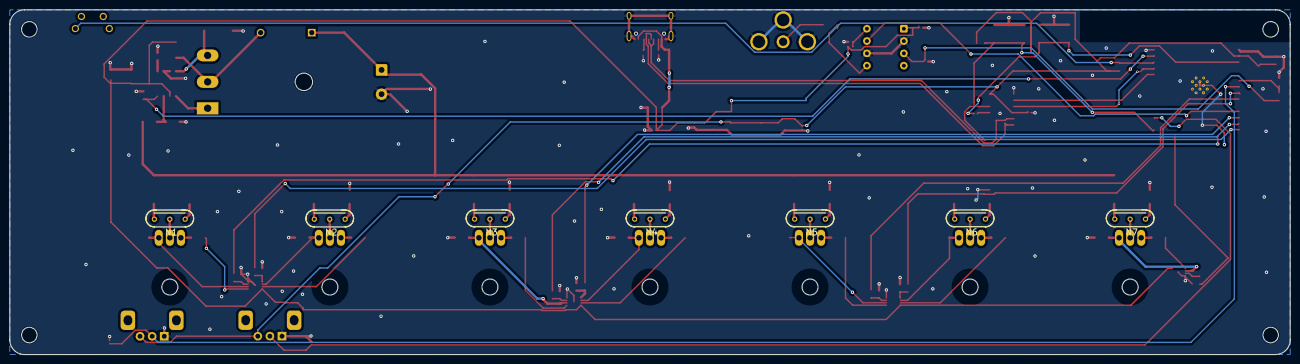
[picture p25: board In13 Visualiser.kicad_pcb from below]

Board: 2 copper layers, 264.2 x 71.1 mm, 115 parts (7 on the bottom side), 85 nets.

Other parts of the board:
Hole1, Hole2, Hole3, Hole4: MountingHole_3.2mm_M3

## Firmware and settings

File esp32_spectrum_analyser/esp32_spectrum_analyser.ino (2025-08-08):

#include <Arduino.h>
#include <WiFi.h>
#include <WebServer.h>
#include <EEPROM.h>
#include <WiFiUdp.h>
#include <ArduinoJson.h>
#include <MSGEQ7.h>
#include "freertos/FreeRTOS.h"
#include "freertos/task.h"

// ===========================
// Hardware configuration
// ===========================
// Adjust these pin assignments to match your wiring
// MSGEQ7 connections (shared reset & strobe, one analog out)
static constexpr uint8_t PIN_MSGEQ7_RESET = 26;   // any digital pin
static constexpr uint8_t PIN_MSGEQ7_STROBE = 25;  // any digital pin
static constexpr uint8_t PIN_MSGEQ7_ANALOG = 34;  // IO34

// Tube output PWM pins (7 tubes)
static constexpr uint8_t TUBE_PINS[7] = {13, 12, 14, 27, 33, 32, 15};

// PSU enable control pin (active HIGH assumed)
static constexpr uint8_t PIN_PSU_ENABLE = 23;

// Power button (active LOW with pull-up). Use external pull-up if using input-only pins.
static constexpr uint8_t PIN_POWER_BUTTON = 22;

// Potentiometers (10k, reversed so high resistance yields 0)
static constexpr uint8_t PIN_POT_GAIN = 35;  // IO35
static constexpr uint8_t PIN_POT2 = 16;      // IO16 (spare)

// ===========================
// PWM (LEDC) configuration
// ===========================
static constexpr uint8_t LEDC_CHANNEL_TUBES[7] = {0, 1, 2, 3, 4, 5, 6};
static constexpr uint32_t LEDC_FREQ_TUBE = 20000;      // 20 KHz for height control
static constexpr uint8_t LEDC_RES_BITS = 12;           // 0..4095
static constexpr uint16_t LEDC_MAX = (1 << LEDC_RES_BITS) - 1; // 4095

// Dual-core sync
portMUX_TYPE g_mux = portMUX_INITIALIZER_UNLOCKED;
volatile bool g_newBandsReady = false;
TaskHandle_t g_audioTaskHandle = nullptr;



// ===========================
// MSGEQ7 library object (NicoHood/MSGEQ7)
// ===========================
// Smoothing: 191 (~75%) recommended if smoothing desired
CMSGEQ7<191, PIN_MSGEQ7_RESET, PIN_MSGEQ7_STROBE, PIN_MSGEQ7_ANALOG> MSGEQ7;

// Reads per second limit (configurable 1..7 from panel, default 5)
static uint8_t g_updatesPerSecond = 5; // 1..7 limited by settings mode
#define MSGEQ7_INTERVAL ReadsPerSecond(g_updatesPerSecond)

// ===========================
// Runtime state
// ===========================
bool g_isOn = false;                // device power state
bool g_inCalibration = false;       // calibration mode active
uint8_t g_calibIndex = 0;           // which tube we are calibrating 0..6
bool g_inSettings = false;          // settings mode active
bool g_mirrorMode = false;          // experimental mirror mode

// Track last audio time for auto-off
uint32_t g_lastLoudMs = 0;
static constexpr uint32_t AUTO_OFF_MS = 5UL * 60UL * 1000UL; // 5 minutes

// Auto-on threshold on detected audio
static uint8_t g_audioThreshold = 25; // noise floor ~20 in 8-bit; adjust via web

// Volume gain (from pot). We'll map pot to 0.25..2.0
float g_volumeGain = 1.0f;



// Calibration maxima per tube (0..4095 for PWM duty)
uint16_t g_tubeMaxDuty[7] = {4095,4095,4095,4095,4095,4095,4095};

// For power-toggle rapid reset (10 toggles in 2 minutes)
static constexpr uint8_t TOGGLE_RESET_COUNT = 10;
static constexpr uint32_t TOGGLE_WINDOW_MS = 2UL * 60UL * 1000UL;
uint32_t g_toggleTimestamps[TOGGLE_RESET_COUNT] = {0};
uint8_t g_toggleIdx = 0;

// ===========================
// WiFi / Web
// ===========================
WebServer server(80);
WiFiUDP udp;
static constexpr uint16_t UDP_PORT = 4210;

String g_deviceName;
String g_lastWifiSsid;
String g_lastWifiPass;

// Pairing (store up to 5 peers)
static constexpr uint8_t MAX_PEERS = 5;
IPAddress g_peers[MAX_PEERS];
uint8_t g_peerCount = 0;

// ===========================
// EEPROM layout (ESP32 emulated)
// ===========================
// We'll allocate 1024 bytes and manage offsets manually
static constexpr size_t EEPROM_SIZE = 1024;
// Layout:
// 0x00: signature 'S','A','1'
// 0x03: flags (bit0: mirrorMode)
// 0x04..0x13: tubeMaxDuty[7] as uint16_t (14 bytes)
// 0x18: updatesPerSecond (1 byte)
// 0x19: audioThreshold (1 byte)
// 0x1A..0x2F: peers (5 * 4 bytes)
// 0x30: peerCount (1 byte)
// 0x40..0x9F: wifi ssid (96 bytes)
// 0xA0..0xFF: wifi pass (96 bytes)

static constexpr int EE_OFFS_SIGNATURE = 0x00;
static constexpr int EE_OFFS_FLAGS = 0x03;
static constexpr int EE_OFFS_TUBE_MAX = 0x04; // 14 bytes
static constexpr int EE_OFFS_UPS = 0x18;
static constexpr int EE_OFFS_THRESH = 0x19;
static constexpr int EE_OFFS_PEERS = 0x1A; // 20 bytes
static constexpr int EE_OFFS_PEERCOUNT = 0x30;
static constexpr int EE_OFFS_WIFI_SSID = 0x40; // len 96
static constexpr int EE_OFFS_WIFI_PASS = 0xA0; // len 96

// ===========================
// Utilities
// ===========================
static inline uint32_t nowMs() { return millis(); }

static void eepromWriteBytes(int addr, const uint8_t* data, size_t len) {
  for (size_t i = 0; i < len; ++i) EEPROM.write(addr + i, data[i]);
}
static void eepromReadBytes(int addr, uint8_t* out, size_t len) {
  for (size_t i = 0; i < len; ++i) out[i] = EEPROM.read(addr + i);
}

static void eepromWriteString(int addr, const String& s, size_t maxLen) {
  size_t n = min(s.length(), maxLen - 1);
  for (size_t i = 0; i < n; ++i) EEPROM.write(addr + i, (uint8_t)s[i]);
  EEPROM.write(addr + n, 0);
  for (size_t i = n + 1; i < maxLen; ++i) EEPROM.write(addr + i, 0);
}
static String eepromReadString(int addr, size_t maxLen) {
  String s;
  for (size_t i = 0; i < maxLen; ++i) {
    uint8_t c = EEPROM.read(addr + i);
    if (c == 0) break;
    s += (char)c;
  }
  return s;
}

static void saveSettingsToEEPROM() {
  EEPROM.write(EE_OFFS_SIGNATURE + 0, 'S');
  EEPROM.write(EE_OFFS_SIGNATURE + 1, 'A');
  EEPROM.write(EE_OFFS_SIGNATURE + 2, '1');
  uint8_t flags = 0;
  if (g_mirrorMode) flags |= 0x01;
  EEPROM.write(EE_OFFS_FLAGS, flags);
  for (uint8_t i = 0; i < 7; ++i) {
    uint16_t v = g_tubeMaxDuty[i];
    EEPROM.write(EE_OFFS_TUBE_MAX + i * 2 + 0, (uint8_t)(v & 0xFF));
    EEPROM.write(EE_OFFS_TUBE_MAX + i * 2 + 1, (uint8_t)(v >> 8));
  }
  EEPROM.write(EE_OFFS_UPS, g_updatesPerSecond);
  EEPROM.write(EE_OFFS_THRESH, g_audioThreshold);
  // peers
  for (uint8_t i = 0; i < MAX_PEERS; ++i) {
    uint32_t ip = (i < g_peerCount) ? (uint32_t)g_peers[i] : 0;
    EEPROM.write(EE_OFFS_PEERS + i * 4 + 0, (uint8_t)(ip & 0xFF));
    EEPROM.write(EE_OFFS_PEERS + i * 4 + 1, (uint8_t)((ip >> 8) & 0xFF));
    EEPROM.write(EE_OFFS_PEERS + i * 4 + 2, (uint8_t)((ip >> 16) & 0xFF));
    EEPROM.write(EE_OFFS_PEERS + i * 4 + 3, (uint8_t)((ip >> 24) & 0xFF));
  }
  EEPROM.write(EE_OFFS_PEERCOUNT, g_peerCount);
  eepromWriteString(EE_OFFS_WIFI_SSID, g_lastWifiSsid, 96);
  eepromWriteString(EE_OFFS_WIFI_PASS, g_lastWifiPass, 96);
  EEPROM.commit();
}

static void loadSettingsFromEEPROM() {
  if (EEPROM.read(EE_OFFS_SIGNATURE + 0) == 'S' &&
      EEPROM.read(EE_OFFS_SIGNATURE + 1) == 'A' &&
      EEPROM.read(EE_OFFS_SIGNATURE + 2) == '1') {
    uint8_t flags = EEPROM.read(EE_OFFS_FLAGS);
    g_mirrorMode = (flags & 0x01) != 0;
    for (uint8_t i = 0; i < 7; ++i) {
      uint8_t l = EEPROM.read(EE_OFFS_TUBE_MAX + i * 2 + 0);
      uint8_t h = EEPROM.read(EE_OFFS_TUBE_MAX + i * 2 + 1);
      uint16_t v = (uint16_t)l | ((uint16_t)h << 8);
      if (v == 0 || v > LEDC_MAX) v = LEDC_MAX;
      g_tubeMaxDuty[i] = v;
    }
    uint8_t ups = EEPROM.read(EE_OFFS_UPS);
    if (ups >= 1 && ups <= 7) g_updatesPerSecond = ups; else g_updatesPerSecond = 5;
    uint8_t thr = EEPROM.read(EE_OFFS_THRESH);
    g_audioThreshold = thr == 0 ? 25 : thr;
    // peers
    g_peerCount = EEPROM.read(EE_OFFS_PEERCOUNT);
    if (g_peerCount > MAX_PEERS) g_peerCount = 0;
    for (uint8_t i = 0; i < g_peerCount; ++i) {
      uint32_t ip = 0;
      ip |= (uint32_t)EEPROM.read(EE_OFFS_PEERS + i * 4 + 0);
      ip |= (uint32_t)EEPROM.read(EE_OFFS_PEERS + i * 4 + 1) << 8;
      ip |= (uint32_t)EEPROM.read(EE_OFFS_PEERS + i * 4 + 2) << 16;
      ip |= (uint32_t)EEPROM.read(EE_OFFS_PEERS + i * 4 + 3) << 24;
      g_peers[i] = IPAddress(ip);
    }
    g_lastWifiSsid = eepromReadString(EE_OFFS_WIFI_SSID, 96);
    g_lastWifiPass = eepromReadString(EE_OFFS_WIFI_PASS, 96);
  }
}

static void eraseCalibration() {
  for (uint8_t i = 0; i < 7; ++i) g_tubeMaxDuty[i] = LEDC_MAX;
  saveSettingsToEEPROM();
}

static void eraseSettingsKeepCalibration() {
  bool prevMirror = g_mirrorMode;
  uint16_t prevMax[7];
  for (uint8_t i = 0; i < 7; ++i) prevMax[i] = g_tubeMaxDuty[i];
  // clear EEPROM
  for (int i = 0; i < (int)EEPROM_SIZE; ++i) EEPROM.write(i, 0);
  EEPROM.commit();
  // restore calib fields
  g_mirrorMode = prevMirror;
  for (uint8_t i = 0; i < 7; ++i) g_tubeMaxDuty[i] = prevMax[i];
  saveSettingsToEEPROM();
}

static void resetWifiCredentials() {
  g_lastWifiSsid = "";
  g_lastWifiPass = "";
  saveSettingsToEEPROM();
}

// ===========================
// LEDC helpers
// ===========================
static void ledcInitAll() {
  // tube channels
  for (uint8_t i = 0; i < 7; ++i) {
    ledcSetup(LEDC_CHANNEL_TUBES[i], LEDC_FREQ_TUBE, LEDC_RES_BITS);
    ledcAttachPin(TUBE_PINS[i], LEDC_CHANNEL_TUBES[i]);
    ledcWrite(LEDC_CHANNEL_TUBES[i], 0);
  }
}

static void setTubeDuty(uint8_t idx, uint16_t duty) {
  if (idx >= 7) return;
  duty = min<uint16_t>(duty, g_tubeMaxDuty[idx]);
  if (duty > LEDC_MAX) duty = LEDC_MAX;
  ledcWrite(LEDC_CHANNEL_TUBES[idx], duty);
}

static void clearAllTubes() {
  for (uint8_t i = 0; i < 7; ++i) ledcWrite(LEDC_CHANNEL_TUBES[i], 0);
}

// ===========================
// Button handling
// ===========================
static constexpr uint32_t DEBOUNCE_MS = 30;
static constexpr uint32_t CLICK_WINDOW_MS = 1000; // 1s triple-click window
static constexpr uint32_t LONG_PRESS_MS = 1200;

bool btnLastLevel = true; // pull-up, true=HIGH (released)
uint32_t btnLastChangeMs = 0;
uint32_t btnPressStartMs = 0;
uint8_t btnClickCount = 0;
uint32_t btnFirstClickMs = 0;

static void handleButton() {
  bool level = digitalRead(PIN_POWER_BUTTON); // HIGH: released, LOW: pressed (active low)
  uint32_t now = nowMs();
  if (level != btnLastLevel && (now - btnLastChangeMs) > DEBOUNCE_MS) {
    btnLastLevel = level;
    btnLastChangeMs = now;
    if (!level) { // pressed
      btnPressStartMs = now;
    } else { // released
      uint32_t pressDur = now - btnPressStartMs;
      // In calibration: any short release advances immediately
      if (g_inCalibration) {
        advanceCalibrationOnShortClick();
        return;
      }
      // In settings: any short release saves & exits immediately
      if (g_inSettings) {
        saveSettingsAndExit();
        return;
      }
      // Normal mode
      if (pressDur >= LONG_PRESS_MS) {
        // long press: open settings
        g_inSettings = true;
        g_inCalibration = false;
        g_isOn = true;
        digitalWrite(PIN_PSU_ENABLE, HIGH);
      } else {
        // short click for sequence (single/tiple)
        if (btnClickCount == 0) btnFirstClickMs = now;
        btnClickCount++;
      }
    }
  }
  // Evaluate click sequences (only when not in special modes)
  if (!g_inCalibration && !g_inSettings && btnClickCount > 0 && (now - btnFirstClickMs) > CLICK_WINDOW_MS) {
    uint8_t n = btnClickCount;
    btnClickCount = 0;
    if (n >= 3) {
      // triple click -> calibration mode
      g_inCalibration = true;
      g_inSettings = false;
      g_calibIndex = 0;
      g_isOn = true;
      digitalWrite(PIN_PSU_ENABLE, HIGH);
      clearAllTubes();
    } else if (n == 1) {
      // single click -> toggle power
      g_isOn = !g_isOn;
      digitalWrite(PIN_PSU_ENABLE, g_isOn ? HIGH : LOW);
      if (!g_isOn) clearAllTubes();
      // track toggles for WiFi reset logic
      g_toggleTimestamps[g_toggleIdx] = now;
      g_toggleIdx = (g_toggleIdx + 1) % TOGGLE_RESET_COUNT;
    }
  }
  // Check rapid toggles in window
  uint8_t count = 0;
  for (uint8_t i = 0; i < TOGGLE_RESET_COUNT; ++i) {
    if (now - g_toggleTimestamps[i] <= TOGGLE_WINDOW_MS && g_toggleTimestamps[i] != 0) count++;
  }
  if (count >= TOGGLE_RESET_COUNT) {
    // reset WiFi creds, start AP if necessary
    for (uint8_t i = 0; i < TOGGLE_RESET_COUNT; ++i) g_toggleTimestamps[i] = 0;
    resetWifiCredentials();
    if (WiFi.getMode() != WIFI_AP) {
      WiFi.disconnect(true, true);
      delay(200);
      WiFi.mode(WIFI_AP);
      String ssid = g_deviceName;
      ssid += "-Setup";
      WiFi.softAP(ssid.c_str());
    }
  }
}

// ===========================
// Audio reading & tube update
// ===========================
static uint8_t g_lastBands[7] = {0};

static void updatePots() {
  // Pot orientation reversed; scale and invert
  int rawV = analogRead(PIN_POT_GAIN);
  float v = 1.0f - (float)rawV / 4095.0f;
  // Smooth a bit (optional)
  static float sv = 1.0f;
  sv = sv * 0.85f + v * 0.15f;
  g_volumeGain = 0.25f + sv * 1.75f; // 0.25..2.0
}

static void applyBandsToTubes(const uint8_t bands[7]) {
  for (uint8_t i = 0; i < 7; ++i) {
    // Map 0..255 band value to 0..LEDC_MAX duty, apply per-tube calibration
    uint16_t duty = (uint16_t)((bands[i] / 255.0f) * LEDC_MAX);
    setTubeDuty(i, duty);
  }
}

static bool isAudioLoud(const uint8_t bands[7]) {
  // Compute a simple average
  uint16_t sum = 0;
  for (uint8_t i = 0; i < 7; ++i) sum += bands[i];
  uint8_t avg = sum / 7;
  return avg >= g_audioThreshold;
}



static void readAudioAndUpdate() {
  bool newReading = MSGEQ7.read(MSGEQ7_INTERVAL);
  if (!newReading) return;

  uint8_t bands[7];
  for (uint8_t i = 0; i < 7; ++i) {
    uint8_t x = MSGEQ7.get(i);
    x = mapNoise(x);    // remove static noise floor
    float f = min(255.0f, x * g_volumeGain);
    bands[i] = (uint8_t)f;
  }

  // Auto power logic
  if (isAudioLoud(bands)) {
    g_lastLoudMs = nowMs();
    if (!g_isOn) {
      portENTER_CRITICAL(&g_mux);
      g_isOn = true;
      digitalWrite(PIN_PSU_ENABLE, HIGH);
      portEXIT_CRITICAL(&g_mux);
    }
  }
  if (g_isOn && (nowMs() - g_lastLoudMs) > AUTO_OFF_MS) {
    portENTER_CRITICAL(&g_mux);
    g_isOn = false;
    digitalWrite(PIN_PSU_ENABLE, LOW);
    portEXIT_CRITICAL(&g_mux);
    clearAllTubes();
  }

  // Apply locally only if not mirroring and not in UI modes
  if (g_isOn && !g_inCalibration && !g_inSettings && !g_mirrorMode) {
    applyBandsToTubes(bands);
  }

  // Publish new bands snapshot for loop()/UDP to use
  portENTER_CRITICAL(&g_mux);
  memcpy(g_lastBands, bands, 7);
  g_newBandsReady = true;
  portEXIT_CRITICAL(&g_mux);
}

// Audio task pinned to core 0
void audioTask(void* pv) {
  for (;;) {
    // Only analyze when not in calibration/settings; still keep timers running
    readAudioAndUpdate();
    // Small delay to yield; MSGEQ7.read() enforces rate via interval
    vTaskDelay(pdMS_TO_TICKS(2));
  }
}

// ===========================
// Calibration & Settings UIs (panel side)
// ===========================
static void doCalibrationStep() {
  // Illuminate only current tube, others off
  for (uint8_t i = 0; i < 7; ++i) {
    if (i == g_calibIndex) {
      // Use gain pot to set max duty
      int rawV = analogRead(PIN_POT_GAIN);
      float v = 1.0f - (float)rawV / 4095.0f; // reversed
      uint16_t maxDuty = (uint16_t)(v * LEDC_MAX);
      if (maxDuty < 10) maxDuty = 10;
      g_tubeMaxDuty[i] = maxDuty;
      setTubeDuty(i, maxDuty);
    } else {
      setTubeDuty(i, 0);
    }
  }
  // Pressing the power button (short) advances to next tube
  // This is handled in handleButton() which sets g_inCalibration and toggles power.
  // Here, we detect a rising edge of a click by sampling the clickCount logic indirectly.
  // Simpler: we interpret a click by checking for a release that is not long press while in calibration.
  // Implementation detail: we'll reuse the short click handler by checking and advancing in the button evaluation window end.
  // To keep logic simple, we detect a short press release and then if currently in calibration, we advance.
}

static void advanceCalibrationOnShortClick() {
  if (!g_inCalibration) return;
  g_calibIndex++;
  if (g_calibIndex >= 7) {
    // Finished calibration
    g_inCalibration = false;
    saveSettingsToEEPROM();
    // return to powered on state
    if (!g_isOn) {
      g_isOn = true;
      digitalWrite(PIN_PSU_ENABLE, HIGH);
    }
    clearAllTubes();
  }
}

static void showSettingsRate() {
  // Show current updates per second (1..7) by illuminating that many tubes
  for (uint8_t i = 0; i < 7; ++i) {
    setTubeDuty(i, (i < g_updatesPerSecond) ? (uint16_t)(g_tubeMaxDuty[i]) : 0);
  }
}

static void doSettingsStep() {
  // Use gain pot to select 1..7
  int rawV = analogRead(PIN_POT_GAIN);
  float v = 1.0f - (float)rawV / 4095.0f;
  uint8_t sel = (uint8_t)(v * 6.999f) + 1; // 1..7
  if (sel < 1) sel = 1; if (sel > 7) sel = 7;
  g_updatesPerSecond = sel;
  showSettingsRate();
}

static void saveSettingsAndExit() {
  g_inSettings = false;
  saveSettingsToEEPROM();
  clearAllTubes();
}

// ===========================
// UDP discovery & pairing
// ===========================
static void udpSendAnnounce(IPAddress dest) {
  // Packet: 'S','A','A', nameLen(1), name
  char name[32];
  g_deviceName.toCharArray(name, sizeof(name));
  uint8_t nameLen = strnlen(name, sizeof(name));
  uint8_t hdr[4] = {'S','A','A', nameLen};
  udp.beginPacket(dest, UDP_PORT);
  udp.write(hdr, sizeof(hdr));
  udp.write((uint8_t*)name, nameLen);
  udp.endPacket();
}

static void udpBroadcastDiscover() {
  // Packet: 'S','A','Q'
  uint8_t buf[3] = {'S','A','Q'};
  IPAddress bcast(255,255,255,255);
  udp.beginPacket(bcast, UDP_PORT);
  udp.write(buf, sizeof(buf));
  udp.endPacket();
}

static void udpHandle() {
  int psize = udp.parsePacket();
  if (psize <= 0) return;
  IPAddress remote = udp.remoteIP();
  uint8_t buf[64];
  int len = udp.read(buf, sizeof(buf));
  if (len < 3) return;
  // DISCOVER QUERY
  if (buf[0]=='S' && buf[1]=='A' && buf[2]=='Q') {
    // Respond with announce
    udpSendAnnounce(remote);
    return;
  }
  // ANNOUNCE
  if (buf[0]=='S' && buf[1]=='A' && buf[2]=='A' && len >= 4) {
    uint8_t nameLen = buf[3];
    // Store in a temporary discovered list (for simplicity we reuse peers if space)
    bool exists = false;
    for (uint8_t i = 0; i < g_peerCount; ++i) if (g_peers[i] == remote) exists = true;
    if (!exists && g_peerCount < MAX_PEERS) {
      g_peers[g_peerCount++] = remote;
      saveSettingsToEEPROM();
    }
    return;
  }
  // DATA
  if (buf[0]=='S' && buf[1]=='A' && buf[2]=='D' && len >= 11) {
    bool remoteOn = buf[3] != 0;
    uint8_t rbands[7];
    for (uint8_t i = 0; i < 7; ++i) rbands[i] = buf[4+i];
    if (remoteOn && !g_isOn) {
      // Turn on if peer detects audio first
      g_isOn = true;
      digitalWrite(PIN_PSU_ENABLE, HIGH);
    }
    if (g_mirrorMode) {
      // Mirror bands
      memcpy(g_lastBands, rbands, 7);
      if (g_isOn && !g_inCalibration && !g_inSettings) applyBandsToTubes(rbands);
    }
    return;
  }
}

// ===========================
// WiFi connect/AP
// ===========================
static void startAP() {
  String ssid = g_deviceName + "-Setup";
  WiFi.mode(WIFI_AP);
  WiFi.softAP(ssid.c_str());
}

static void connectWiFiOrAP() {
  if (g_lastWifiSsid.length() == 0) {
    startAP();
    return;
  }
  WiFi.mode(WIFI_STA);
  WiFi.begin(g_lastWifiSsid.c_str(), g_lastWifiPass.c_str());
  uint32_t t0 = nowMs();
  while (WiFi.status() != WL_CONNECTED && (nowMs() - t0) < 15000) {
    delay(100);
  }
  if (WiFi.status() != WL_CONNECTED) {
    startAP();
  }
}
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
void loop() {
  // Handle web
  server.handleClient();
  // Handle UDP receive
  udpHandle();


  // Pots and buttons on core 1
  updatePots();
  handleButton();

  // Keep PSU on during UI modes
  if (g_inCalibration || g_inSettings) {
    if (!g_isOn) {
      portENTER_CRITICAL(&g_mux);
      g_isOn = true;
      digitalWrite(PIN_PSU_ENABLE, HIGH);
      portEXIT_CRITICAL(&g_mux);
    }
  }

  // UI mode visuals
  if (g_inCalibration) {
    doCalibrationStep();
  }
  if (g_inSettings) {
    doSettingsStep();
  }

  // Mirror/peer notify from core 1 to avoid UDP concurrency with receive
  if (g_peerCount > 0 && !g_mirrorMode) {
    bool sendNow = false;
    uint8_t bands[7];
    portENTER_CRITICAL(&g_mux);
    if (g_newBandsReady) {
      memcpy(bands, g_lastBands, 7);
      g_newBandsReady = false;
      sendNow = true;
    }
    portEXIT_CRITICAL(&g_mux);
    if (sendNow) {
      uint8_t buf[11];
      buf[0] = 'S'; buf[1] = 'A'; buf[2] = 'D';
      buf[3] = g_isOn ? 1 : 0;
      for (uint8_t i = 0; i < 7; ++i) buf[4 + i] = bands[i];
      for (uint8_t i = 0; i < g_peerCount; ++i) {
        udp.beginPacket(g_peers[i], UDP_PORT);
        udp.write(buf, 11);
        udp.endPacket();
      }
    }
  }

  // Normal audio update moved to audio task
}

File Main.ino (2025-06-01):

const int MSGEQ7_STROBE_PIN = 25;
const int MSGEQ7_RESET_PIN = 26;
const int MSGEQ7_OUT_PIN = 34;

const int NIXIE_CTRL_PINS[] = {13, 12, 14, 27, 33, 32, 15};
const int NUM_BANDS = 7;

const int VOLUME_POT_PIN = 35;
const int BRIGHTNESS_POT_PIN = 36;
const int ESP32_HV_CONTROL_PIN = 23;

const int PWM_FREQ = 5000;
const int PWM_RESOLUTION = 8;
int ledc_channels[NUM_BANDS];

int band_values[NUM_BANDS];

const unsigned long INACTIVITY_TIMEOUT_MS = 4 * 60 * 1000;
unsigned long last_activity_time = 0;
bool tubes_are_on = true;

const int ADC_MAX = 4095;
const int PWM_MAX = (1 << PWM_RESOLUTION) - 1;

const int ACTIVITY_NOISE_THRESHOLD = 50;

void setup() {
  Serial.begin(115200);
  Serial.println("Starting...");

  pinMode(MSGEQ7_STROBE_PIN, OUTPUT);
  pinMode(MSGEQ7_RESET_PIN, OUTPUT);
  pinMode(ESP32_HV_CONTROL_PIN, OUTPUT);

  digitalWrite(MSGEQ7_RESET_PIN, LOW);
  digitalWrite(MSGEQ7_STROBE_PIN, HIGH);
  digitalWrite(ESP32_HV_CONTROL_PIN, HIGH);

  for (int i = 0; i < NUM_BANDS; i++) {
    ledc_channels[i] = i;
    ledcSetup(ledc_channels[i], PWM_FREQ, PWM_RESOLUTION);
    ledcAttachPin(NIXIE_CTRL_PINS[i], ledc_channels[i]);
  }

  digitalWrite(MSGEQ7_RESET_PIN, HIGH);
  delayMicroseconds(5);
  digitalWrite(MSGEQ7_RESET_PIN, LOW);
  delayMicroseconds(75);

  last_activity_time = millis();
  tubes_are_on = true;

  Serial.println("Initialized.");
}

void readMSGEQ7() {
  digitalWrite(MSGEQ7_RESET_PIN, HIGH);
  delayMicroseconds(5);
  digitalWrite(MSGEQ7_RESET_PIN, LOW);
  delayMicroseconds(75);

  for (int i = 0; i < NUM_BANDS; i++) {
    digitalWrite(MSGEQ7_STROBE_PIN, LOW);
    delayMicroseconds(36);
    band_values[i] = analogRead(MSGEQ7_OUT_PIN);
    digitalWrite(MSGEQ7_STROBE_PIN, HIGH);
    delayMicroseconds(36);
  }
}

void turnOffTubes() {
  if (tubes_are_on) {
    Serial.println("Sleeping...");
    for (int i = 0; i < NUM_BANDS; i++) {
      ledcWrite(ledc_channels[i], 0);
    }
    digitalWrite(ESP32_HV_CONTROL_PIN, LOW);
  }
}

void updateTubeDisplay(float volume_level, float brightness_level) {
  for (int i = 0; i < NUM_BANDS; i++) {
    float current_band_value = band_values[i];
    float normalized_band = current_band_value / (float)ADC_MAX;
    float volume_adjusted_band = normalized_band * volume_level;
    volume_adjusted_band = constrain(volume_adjusted_band, 0.0, 1.0);
    int pwm_duty = (int)(volume_adjusted_band * brightness_level * PWM_MAX);
    pwm_duty = constrain(pwm_duty, 0, PWM_MAX);
    ledcWrite(ledc_channels[i], pwm_duty);
  }
}

void loop() {
  int raw_volume = analogRead(VOLUME_POT_PIN);
  int raw_brightness = analogRead(BRIGHTNESS_POT_PIN);

  float volume_setting = raw_volume / (float)ADC_MAX;
  float brightness_setting = raw_brightness / (float)ADC_MAX;

  readMSGEQ7();

  int max_band_value_this_cycle = 0;
  for (int i = 0; i < NUM_BANDS; i++) {
    if (band_values[i] > max_band_value_this_cycle) {
      max_band_value_this_cycle = band_values[i];
    }
  }

  if (max_band_value_this_cycle > ACTIVITY_NOISE_THRESHOLD) {
    if (!tubes_are_on) {
      Serial.println("Waking up...");
      digitalWrite(ESP32_HV_CONTROL_PIN, HIGH);
    }
    last_activity_time = millis();
    tubes_are_on = true;
  }

  if (millis() - last_activity_time > INACTIVITY_TIMEOUT_MS) {
    if (tubes_are_on) {
      turnOffTubes();
      tubes_are_on = false;
    }
  }

  if (tubes_are_on) {
    updateTubeDisplay(volume_setting, brightness_setting);
  }

  delay(20);
}

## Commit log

2025-05-18 Power input
2025-05-19 Nixie driver
2025-05-22 PCB 2
2025-05-28 Add case
2025-08-08 Implement ESP32 spectrum analyzer with WiFi, calibration, and web UI
2025-08-08 Update pin assignments and add spare potentiometer input
